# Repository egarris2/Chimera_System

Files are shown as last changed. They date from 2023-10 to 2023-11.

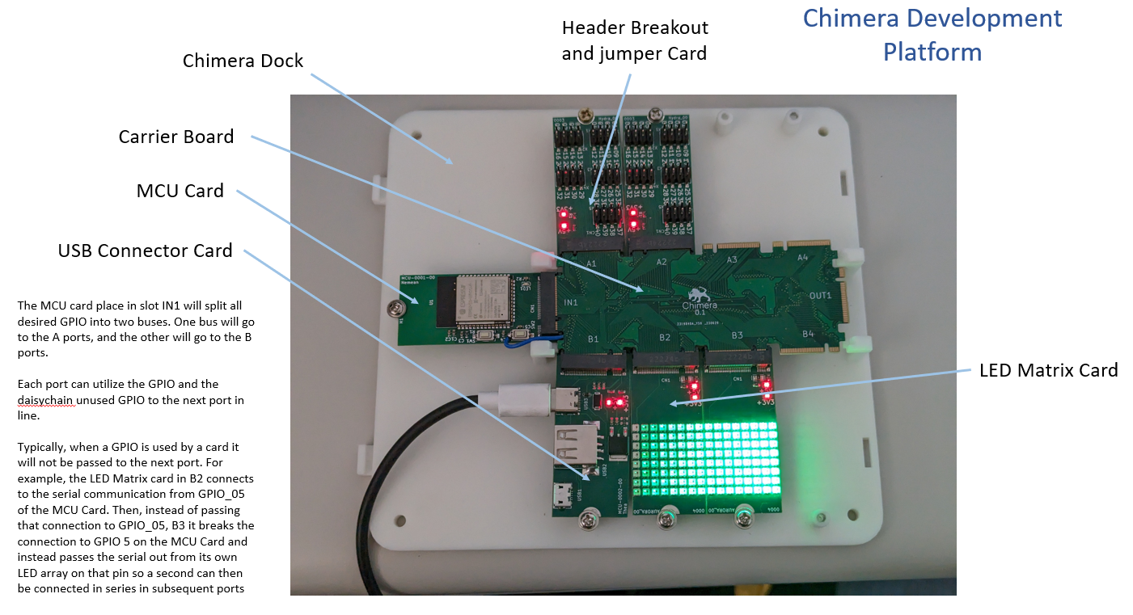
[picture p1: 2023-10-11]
Images/Annotations.png

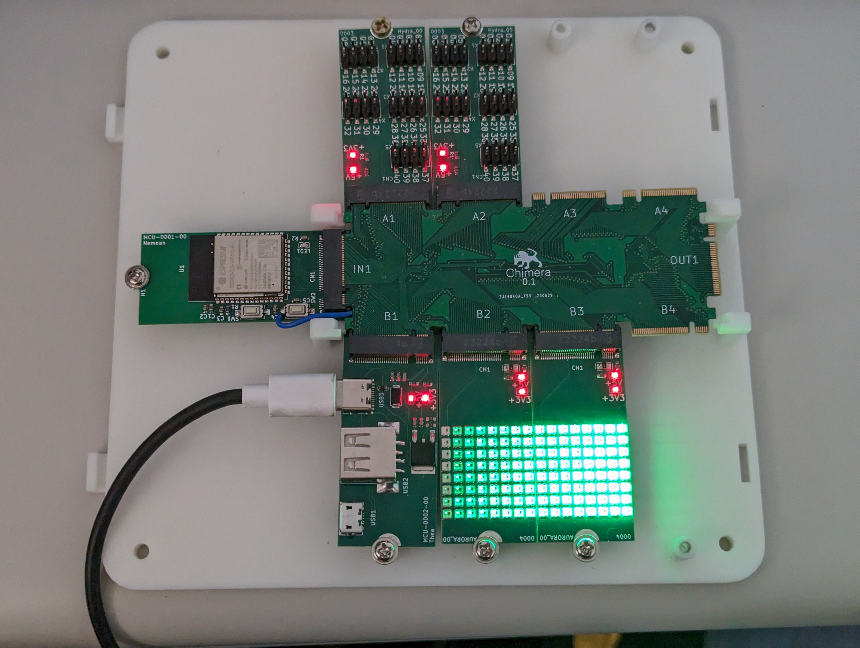
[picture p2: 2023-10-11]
Images/Chimera_System_LEDs.jpg

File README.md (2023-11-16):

View this project on [CADLAB.io](https://cadlab.io/project/27528). 

# Chimera_System
A modular PCB system designed for rapid iteration and extreme flexibility in application.

All PCBs are designed in KiCAD 7. They utilize components that are available from the easyEDA component library which allows for quick generation of manufacturing files for order of assembly from JLCPCB.



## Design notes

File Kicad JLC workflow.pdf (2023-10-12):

Description
This document is a guide to designing a PCBA prototype in Kicad and ordering it through JLCPCB assembly in a way that is quick and easy.

Pre-Requisites and links
Kicad (https://www.kicad.org/) - Open Source EDA software
JLCPCB (https://jlcpcb.com/) - Online PCB fabrication website
JLC Parts Search (https://yaqwsx.github.io/jlcparts/#/) - third party tool for better searching of available SMD assembly parts (github) (https://github.com/yaqwsx/jlcparts) Part import (https://github.com/TousstNicolas/JLC2KiCad_lib) - third party tool for importing JCL component into Kicad Library from command line JLC Export (https://github.com/Bouni/kicad-jlcpcb-tools) - third party tool for exporting BOM and CPL data

Adding JLC compatible parts to Kicad
Search desired components using JLC Parts Search (https://yaqwsx.github.io/jlcparts/#/) to find the LCSC number

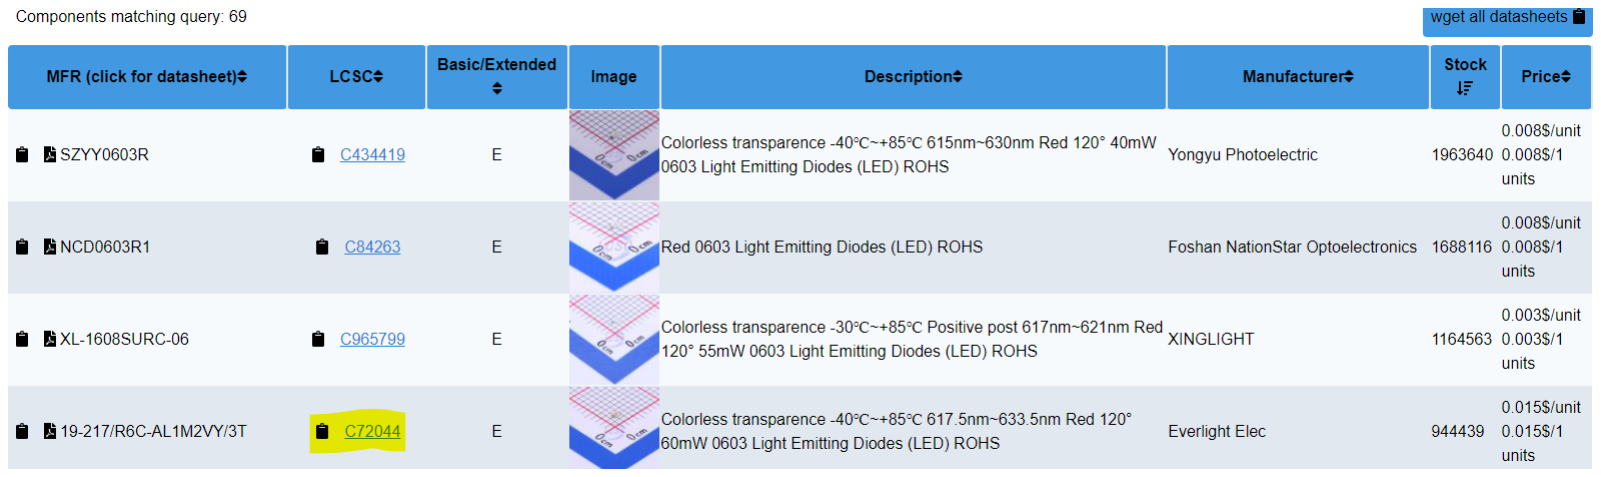
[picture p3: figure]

Import components using Part import. (https://github.com/TousstNicolas/JLC2KiCad_lib)
- Open terminal session in desired directory (e.g. JLC_libraries)
- In the terminal, type command
JLC2KiCadLib C72044 -schematic_lib JLC
- The following folders will be created

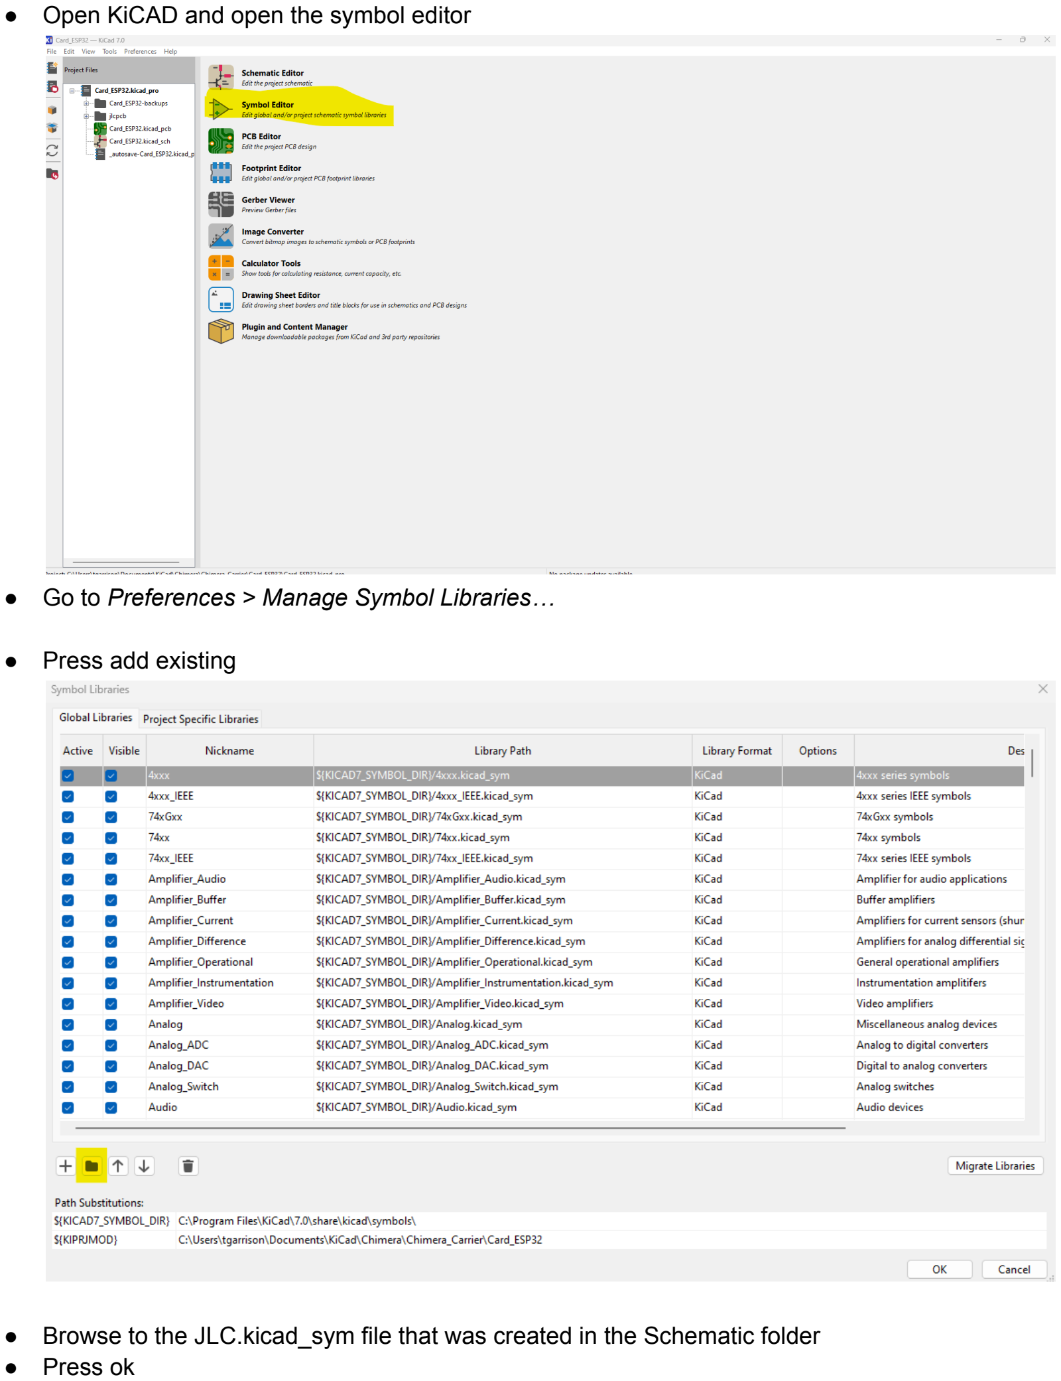
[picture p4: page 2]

- Open KiCAD and open the symbol editor
- Go to Preferences > Manage Symbol Libraries…
- Press add existing
- Browse to the JLC.kicad_sym file that was created in the Schematic folder
- Press ok

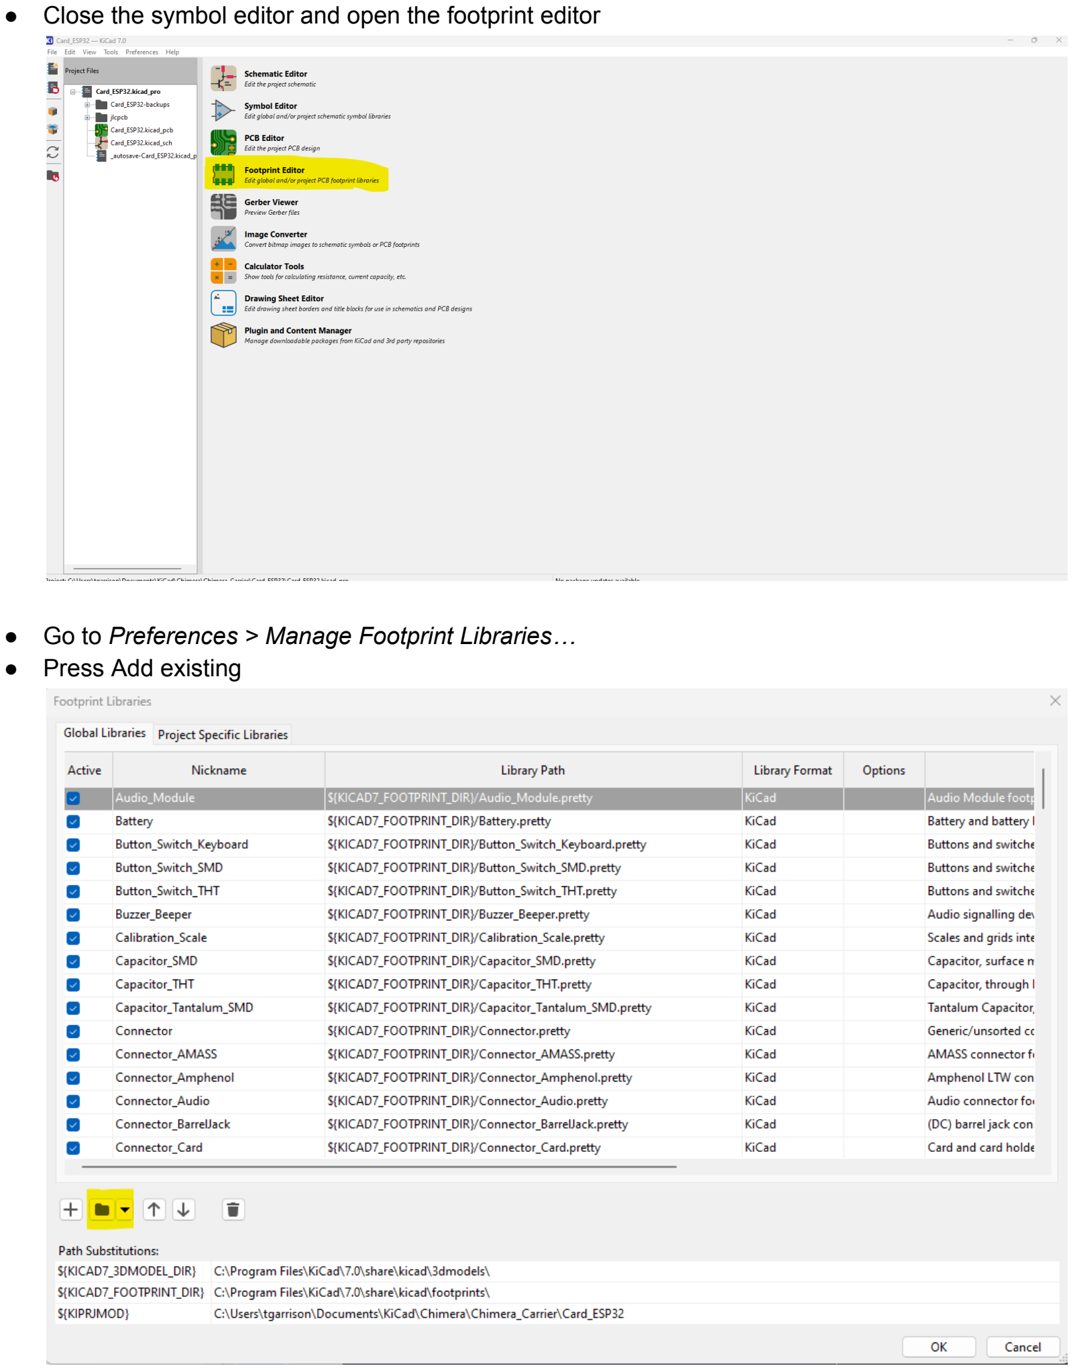
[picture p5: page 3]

- Close the symbol editor and open the footprint editor
- Go to Preferences > Manage Footprint Libraries…
- Press Add existing

- Select the footprint folder that was created (optionally you can give it a nickname)
- Press okay
- To assign the symbol to the footprint, open the symbol editor again
- Select the recently created component/s and open the symbol properties dialogue

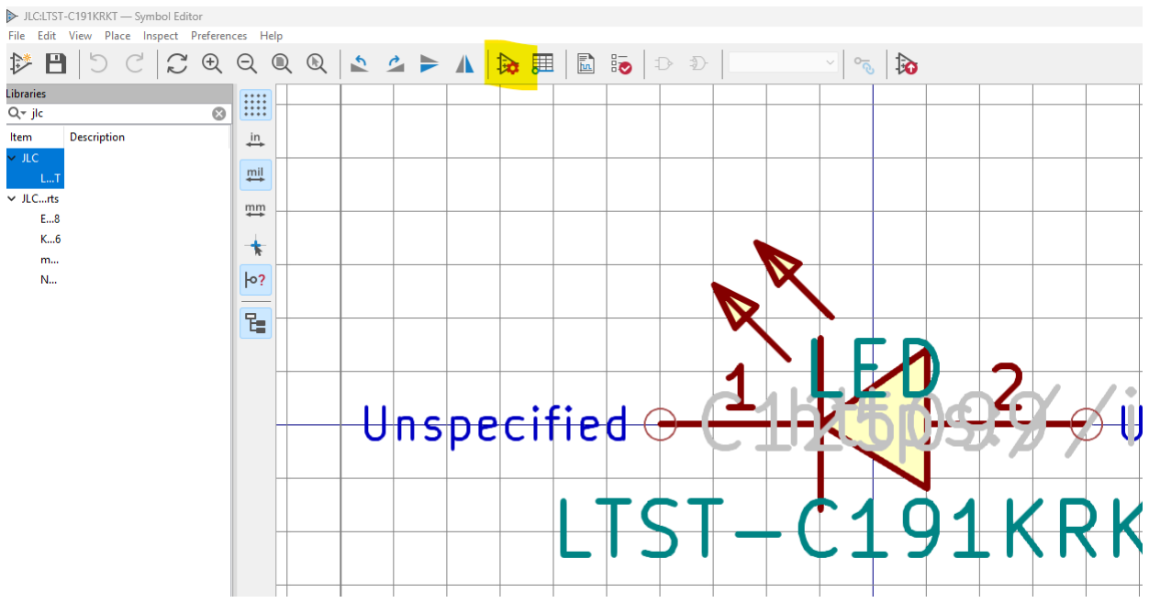
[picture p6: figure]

- Click the icon in the footprint field and select the correct footprint from the previously imported footprint library

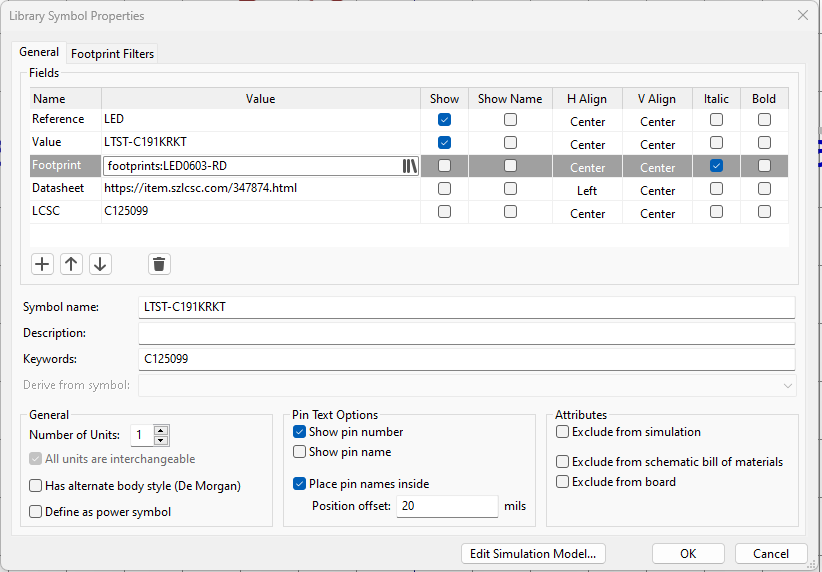
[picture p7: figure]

- This will permanently associate the part with the footprint.
- This step can be eliminated if the created footprint is moved to the Kicad Program files and placed in a footprint.pretty folder .\KiCad\7.0\share\kicad\footprint.pretty (Untested)
- You can now add the part to the schematic with the confidence that when you go to order a prototype from JLCPCB it will automatically be able to be found and assembled when you import BOM and CPL files.

Exporting files for JLC
- After finishing your Kicad Design and are ready to order, you can now press the JLC icon that was added to Kicad after you added the JLC Export (https://github.com/Bouni/kicad-jlcpcb-tools) tool to Kicad.
- Here you can review that all of your parts are recognized as JLC assembly components by their CXXXXX number.
- Press Generate fabrication files and zip them into a folder to drag into JLCPCB (https://jlcpcb.com/) when ready to order. This should let you order the prototype with no further work unless one of the parts you used has gone out of stock.

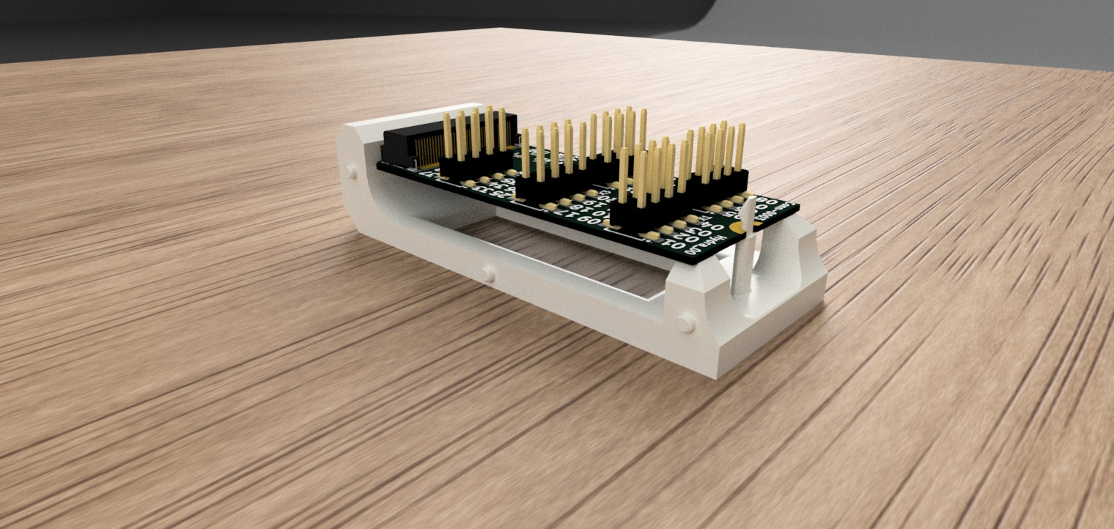
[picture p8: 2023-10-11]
Model_Chimera_Card_Holder/Chimera_Card_Holder_white_nubs.png

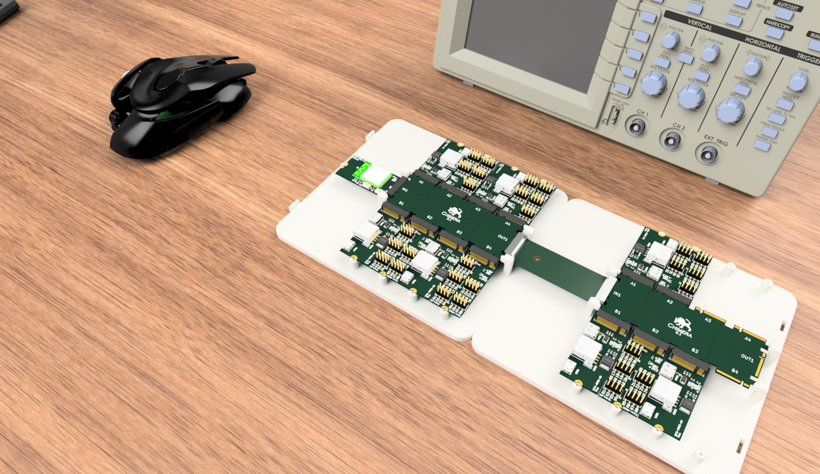
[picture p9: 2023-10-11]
PCB_Chimera_Card_Examples/Chimera_0003_Hydra_CONN_Headers/3D/Chimera_Dock v5.png

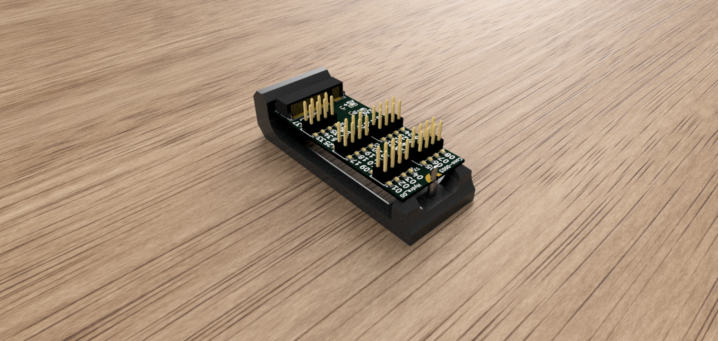
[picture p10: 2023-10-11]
Model_Chimera_Card_Holder/Chimera_Card_Holder_black.png

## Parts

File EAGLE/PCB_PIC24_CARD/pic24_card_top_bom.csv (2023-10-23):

Comment | Designator | Footprint | LCSC Part #
12MHz | Y1 | FA238
3k3 | R5 R6 | R0402_NIBE | C3969551
10k | R1 R4 R7 | R0402_NIBE | C2838653
10u | C10 | C0805 | C882505
16p | C1 C5 | C0402_NIBE | C161307
100n | C2 C3 C4 C6 C7 C8 C9 C11 | C0402_NIBE | C327273
470R | R3 R8 | R0402_NIBE | C606172
820R | R2 | R0402_NIBE | C227421
CONN_SMD_67P-P0.5-V_NASB0-S6701-TS50 | X1 | CONN_SMD_67P-P0.5-V_NASB0-S6701-TS50 | C367024
LED_YELLOW | STATUS | R0603 | C511086
M.2_MKEY_FINGERS | X2 | M.2_MKEY_FINGERS
MOUNTING_3M_3.2MM | M1 | MOUNTING_3M_3.2MM
PIC24FJ256GL410 | IC1 | PIC24FJ256GL410 | C1015827
XR3072XID-F | IC2 | SOIC8

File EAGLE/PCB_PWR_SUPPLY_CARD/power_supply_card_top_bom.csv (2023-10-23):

Comment | Designator | Footprint | LCSC Part #
2R 1W | R3 | R2512 | C105100
4u7 100V | C3 | C1210 | C385987
10u | C13 C14 | C0603 | C4555498603
10u | L1 | L4532P | C99792
10u 50V | C5 C6 C7 C8 | C1210 | C412619
22k | R5 | R0402_NIBE | C416374
47k | R4 R7 | R0402_NIBE | C4076535
100n 50V | C4 C9 C11 | C0603 | C2929177
100u | L2 | ASPI-8040S | C187495
130k | R8 | R0402_NIBE | C4028083
150n | C10 | C0603 | C913573
150n | C12 | C0402_NIBE | C51554
200k | R6 | R0402_NIBE | C2906866
220k | R9 | R0402_NIBE | C168214
470R | R2 | R0603 | C23179
74404063470 | L3 | 74404063470 | C6404593
B72520T0400K062 | R1 | R1206 | C210939
CONN_SMD_67P-P0.5-V_NASB0-S6701-TS50 | X1 | CONN_SMD_67P-P0.5-V_NASB0-S6701-TS50 | C367024
DSS16U | D2 D3 | SOD123F | C3020461
LED_GREEN | LED1 | R0603 | C125099
LIN_REG_ADJ_SOT223 | IC1 | SOT223 | C108496
M.2_MKEY_FINGERS | X2 | M.2_MKEY_FINGERS | na
MOUNTING_3M_3.2MM | M1 | MOUNTING_3M_3.2MM | na
RS1J | D1 | DO-214AC(SMA) | C154794
ST1S14PHR | U1 U2 | HSOP8_STM | C84130
Phoenix | X3 | 1751248 | C89122
220u 50V | C1 | 5p 10d | C134649

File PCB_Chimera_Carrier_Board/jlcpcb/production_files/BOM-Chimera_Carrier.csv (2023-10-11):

Comment | Designator | Footprint | LCSC
Bus_M.2_Socket_B | B1 | NGFF_B
Bus_M.2_Socket_B | A2 | NGFF_B
Bus_M.2_Socket_B | IN1 | NGFF_B
Bus_M.2_Socket_B | OUT1 | NGFF_B
Bus_M.2_Socket_B | A3 | NGFF_B
Bus_M.2_Socket_B | B3 | NGFF_B
Bus_M.2_Socket_B | B2 | NGFF_B
Bus_M.2_Socket_B | B4 | NGFF_B
Bus_M.2_Socket_B | A1 | NGFF_B
Bus_M.2_Socket_B | A4 | NGFF_B

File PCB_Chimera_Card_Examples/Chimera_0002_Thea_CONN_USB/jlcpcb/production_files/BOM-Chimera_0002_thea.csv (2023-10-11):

Comment | Designator | Footprint | LCSC
micro_USBFemale | USB1 | MICRO-USB-SMD_5P-P0.65-H-F_C10418 | C10418
LTST-C191KRKT | LED1,LED2 | LED0603-RD | C125099
GT-USB-7010ASV | U1 | USB-C-SMD_G-SWITCH_GT-USB-7010ASV | C2988369
SMAJ5_0CA_C353441 | U3 | SMA_L4.3-W2.5-LS5.0-BI | C353441
NASB0-S6701-TS50 | CN1 | CONN-SMD_67P-P0.50-V_NASB0-S6701-TS50 | C367024
A_F_LCPTrue_color1_2pillar_C42605 | USB2 | USB-A-SMD_USB-M-32 | C42605
LM317_C77880 | Q1 | TO-252-2_L6.6-W6.1-P4.57-LS9.9-TL-CW | C77880
BSMD0603-050-6V | F1 | F0603 | C883095
MountingHole | H1 | MountingHole_3.2mm_M3_Pad_TopBottom
1n | C3 | C_0603_1608Metric
470R | R3 | R_0603_1608Metric
1n | C4 | C_0603_1608Metric
~ | U2 | NGFF_M
470R | R4 | R_0603_1608Metric
470R | R1 | R_0603_1608Metric
470R | R2 | R_0603_1608Metric
1n | C5 | C_0603_1608Metric
100n | C2 | C_0603_1608Metric
10u | C1 | C_0603_1608Metric

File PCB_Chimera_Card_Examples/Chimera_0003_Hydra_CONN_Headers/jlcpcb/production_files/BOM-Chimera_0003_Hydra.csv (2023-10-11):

Comment | Designator | Footprint | LCSC
LTST-C191KRKT | LED1,LED2 | LED0603-RD | C125099
470R | R1,R2 | R_0603_1608Metric | C23179
PZ254-2-04-S | X1,X2,X3,X4,X5 | HDR-SMD_8P-P2.54-V-M-R2-C4-LS7.4 | C3294462
NASB0-S6701-TS50 | CN1 | CONN-SMD_67P-P0.50-V_NASB0-S6701-TS50 | C367024
MountingHole | H2 | MountingHole_3.2mm_M3_Pad_TopBottom
~ | U2 | NGFF_M

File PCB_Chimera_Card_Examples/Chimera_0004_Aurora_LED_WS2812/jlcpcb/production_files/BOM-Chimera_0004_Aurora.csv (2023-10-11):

Comment | Designator | Footprint | LCSC
LTST-C191KRKT | LED1,LED2 | LED0603-RD | C125099
TLC-PSMD010 | F1 | F0805 | C261939
NASB0-S6701-TS50 | CN1 | CONN-SMD_67P-P0.50-V_NASB0-S6701-TS50 | C367024
WS2812B-2020 | LED10,LED11,LED12,LED13,LED14,LED15,LED16,LED17,LED18,LED19,LED20,LED21,LED22,LED23,LED24,LED25,LED26,LED27,LED28,LED29,LED3,LED30,LED31,LED32,LED33,LED34,LED35,LED36,LED37,LED38,LED39,LED4,LED40,LED41,LED42,LED43,LED44,LED45,LED46,LED47,LED48,LED49,LED5,LED50,LED51,LED52,LED53,LED55,LED56,LED57,LED59,LED6,LED60,LED61,LED63,LED64,LED65,LED67,LED68,LED7,LED71,LED72,LED8,LED9 | LED-SMD_4P-L2.0-W2.0-TL_WS2812B-2020 | C965555
MountingHole | H1 | MountingHole_3.2mm_M3_Pad_TopBottom
100n | C70 | C_0402_1005Metric
100n | C69 | C_0402_1005Metric
100n | C66 | C_0402_1005Metric
100n | C65 | C_0402_1005Metric
100n | C63 | C_0402_1005Metric
100n | C62 | C_0402_1005Metric
100n | C61 | C_0402_1005Metric
100n | C59 | C_0402_1005Metric
100n | C58 | C_0402_1005Metric
100n | C57 | C_0402_1005Metric
100n | C55 | C_0402_1005Metric
100n | C54 | C_0402_1005Metric
100n | C53 | C_0402_1005Metric
100n | C51 | C_0402_1005Metric
100n | C50 | C_0402_1005Metric
100n | C49 | C_0402_1005Metric
100n | C48 | C_0402_1005Metric
100n | C47 | C_0402_1005Metric
100n | C46 | C_0402_1005Metric
100n | C45 | C_0402_1005Metric
100n | C44 | C_0402_1005Metric
100n | C43 | C_0402_1005Metric
100n | C42 | C_0402_1005Metric
100n | C41 | C_0402_1005Metric
100n | C40 | C_0402_1005Metric
100n | C39 | C_0402_1005Metric
100n | C38 | C_0402_1005Metric
100n | C37 | C_0402_1005Metric
100n | C36 | C_0402_1005Metric
100n | C35 | C_0402_1005Metric
100n | C34 | C_0402_1005Metric
100n | C33 | C_0402_1005Metric
100n | C32 | C_0402_1005Metric
100n | C31 | C_0402_1005Metric
100n | C30 | C_0402_1005Metric
100n | C29 | C_0402_1005Metric
100n | C28 | C_0402_1005Metric
100n | C27 | C_0402_1005Metric
100n | C26 | C_0402_1005Metric
100n | C25 | C_0402_1005Metric
100n | C7 | C_0402_1005Metric
100n | C2 | C_0402_1005Metric
100n | C4 | C_0402_1005Metric
100n | C5 | C_0402_1005Metric
100n | C6 | C_0402_1005Metric
100n | C22 | C_0402_1005Metric
100n | C10 | C_0402_1005Metric
100n | C20 | C_0402_1005Metric
100n | C1 | C_0402_1005Metric
100n | C3 | C_0402_1005Metric
100n | C9 | C_0402_1005Metric
100n | C11 | C_0402_1005Metric
100n | C12 | C_0402_1005Metric
100n | C13 | C_0402_1005Metric
100n | C14 | C_0402_1005Metric
100n | C15 | C_0402_1005Metric
100n | C17 | C_0402_1005Metric
100n | C19 | C_0402_1005Metric
100n | C18 | C_0402_1005Metric
100n | C16 | C_0402_1005Metric
100n | C21 | C_0402_1005Metric
100n | C23 | C_0402_1005Metric
100n | C8 | C_0402_1005Metric
100n | C24 | C_0402_1005Metric
~ | U2 | NGFF_M
470R | R1 | R_0603_1608Metric
470R | R2 | R_0603_1608Metric

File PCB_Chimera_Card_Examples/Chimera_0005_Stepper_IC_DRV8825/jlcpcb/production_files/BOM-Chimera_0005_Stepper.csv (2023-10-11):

Comment | Designator | Footprint | LCSC
LTST-C191KRKT | LED1,LED2 | LED0603-RD | C125099
TLC-PSMD010 | F1 | F0805 | C261939
DB126V-5_0-6P-GN | U3 | CONN-TH_DB126V-5.0-6P-GN | C2682301
NASB0-S6701-TS50 | CN1 | CONN-SMD_67P-P0.50-V_NASB0-S6701-TS50 | C367024
DRV8825PWPR | U1 | HTSSOP-28_L9.7-W4.4-P0.65-LS6.4-BL-EP | C81582
0.01 uF | C6 | C_0603_1608Metric
NM | R17 | R_0603_1608Metric
NM | R14 | R_0603_1608Metric
0.2R | R5 | R_0603_1608Metric
~ | U2 | NGFF_M
10k | R7 | R_0603_1608Metric
1M | R3 | R_0603_1608Metric
470R | R1 | R_0603_1608Metric
100 uF | C5 | CP_Elec_6.3x5.4_Nichicon
470R | R2 | R_0603_1608Metric
0.1 uF | C3 | C_0603_1608Metric
NM | R18 | R_0603_1608Metric
0.2R | R4 | R_0603_1608Metric
NM | R13 | R_0603_1608Metric
NM | R23 | R_0603_1608Metric
NM | R10 | R_0603_1608Metric
0.1 uF | C1 | C_0603_1608Metric
10k | R11 | R_0603_1608Metric
0.1 uF | C2 | C_0603_1608Metric
NM | R9 | R_0603_1608Metric
MountingHole | H1 | MountingHole_3.2mm_M3_Pad_TopBottom
3k6 | R8 | R_0603_1608Metric
NM | R19 | R_0603_1608Metric
0.47 uF | C7 | C_0603_1608Metric
47k | R6 | R_0603_1608Metric
NM | R16 | R_0603_1608Metric
10k | R12 | R_0603_1608Metric

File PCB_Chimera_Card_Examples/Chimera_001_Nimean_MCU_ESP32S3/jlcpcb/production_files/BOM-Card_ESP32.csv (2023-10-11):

Comment | Designator | Footprint | LCSC
K2-1107ST-A4SW-06 | SW1,SW2 | KEY-SMD_L6.2-W3.6-LS8.0 | C118141
LTST-C191KRKT | LED1 | LED0603-RD | C125099
10k | R1 | R_0603_1608Metric | C13564
100n | C2,C4,C5 | C_0603_1608Metric | C1591
1u | C3 | C_0603_1608Metric | C1592
1k | R2 | R_0603_1608Metric | C1603
ESP32-S3-WROOM-1-N8 | U1 | WIFIM-SMD_ESP32-S3-WROOM-1-N8 | C2913198
NASB0-S6701-TS50 | CN1 | CONN-SMD_67P-P0.50-V_NASB0-S6701-TS50 | C367024
22u | C1 | C_0603_1608Metric | C59461
~ | U2 | NGFF_M
MountingHole | H1 | MountingHole_2.5mm_Pad_TopBottom

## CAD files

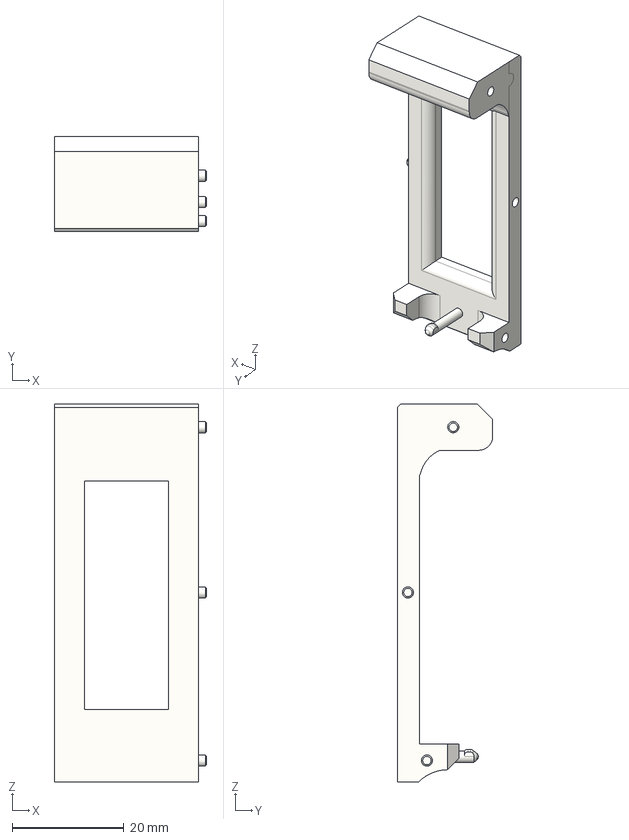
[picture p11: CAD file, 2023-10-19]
Model_Chimera_Card_Holder/Chimera_Card_Holder_03.step
27.2 x 17.0 x 67.6 mm

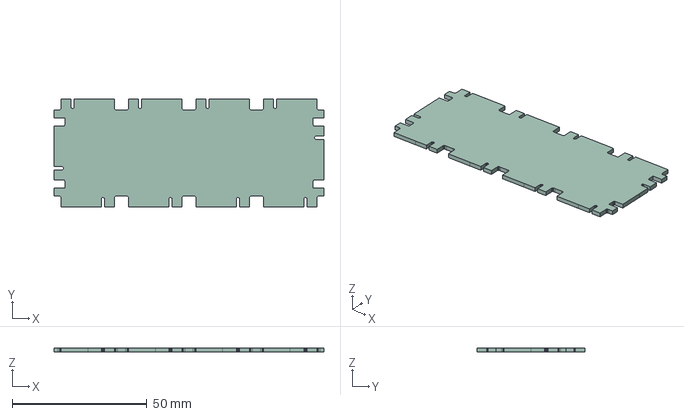
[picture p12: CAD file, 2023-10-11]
PCB_Chimera_Carrier_Board/3D/Chimera_Carrier.step
100.0 x 40.0 x 1.58 mm

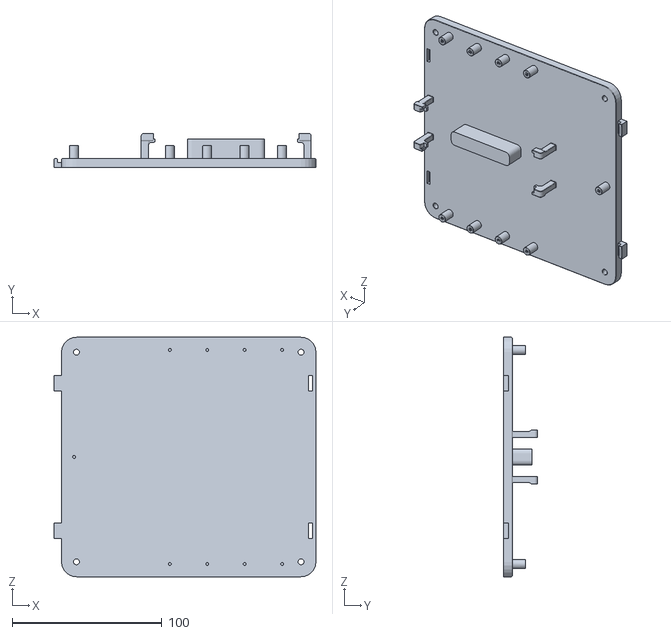
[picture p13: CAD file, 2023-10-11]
Model_Chimera_Dock/Chimera_Dock v6.stl
175.0 x 23.0 x 160.0

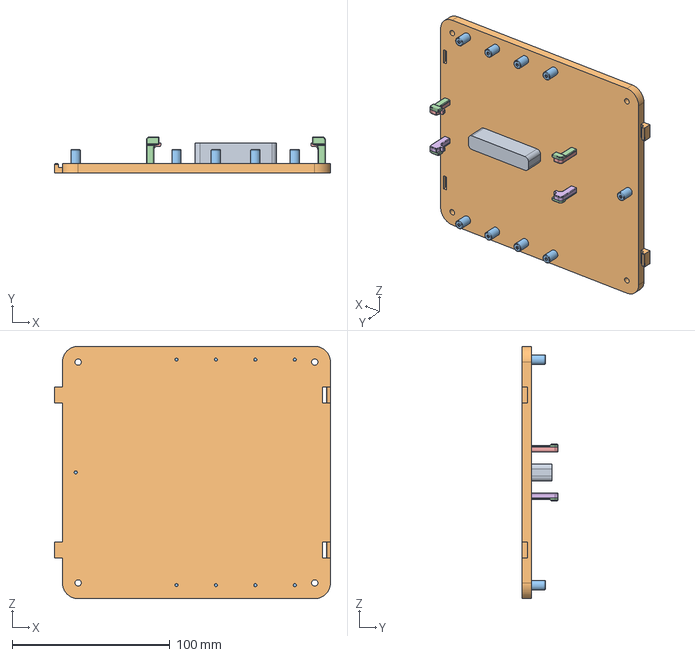
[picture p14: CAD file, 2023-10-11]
Model_Chimera_Dock/Chimera_Dock.step
175.0 x 23.0 x 160.0 mm

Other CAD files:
Model_Chimera_Dock/Chimera_0001_Nimean v1.step
Model_Chimera_Card_Holder/Chimera_Card_Holder_03.stl

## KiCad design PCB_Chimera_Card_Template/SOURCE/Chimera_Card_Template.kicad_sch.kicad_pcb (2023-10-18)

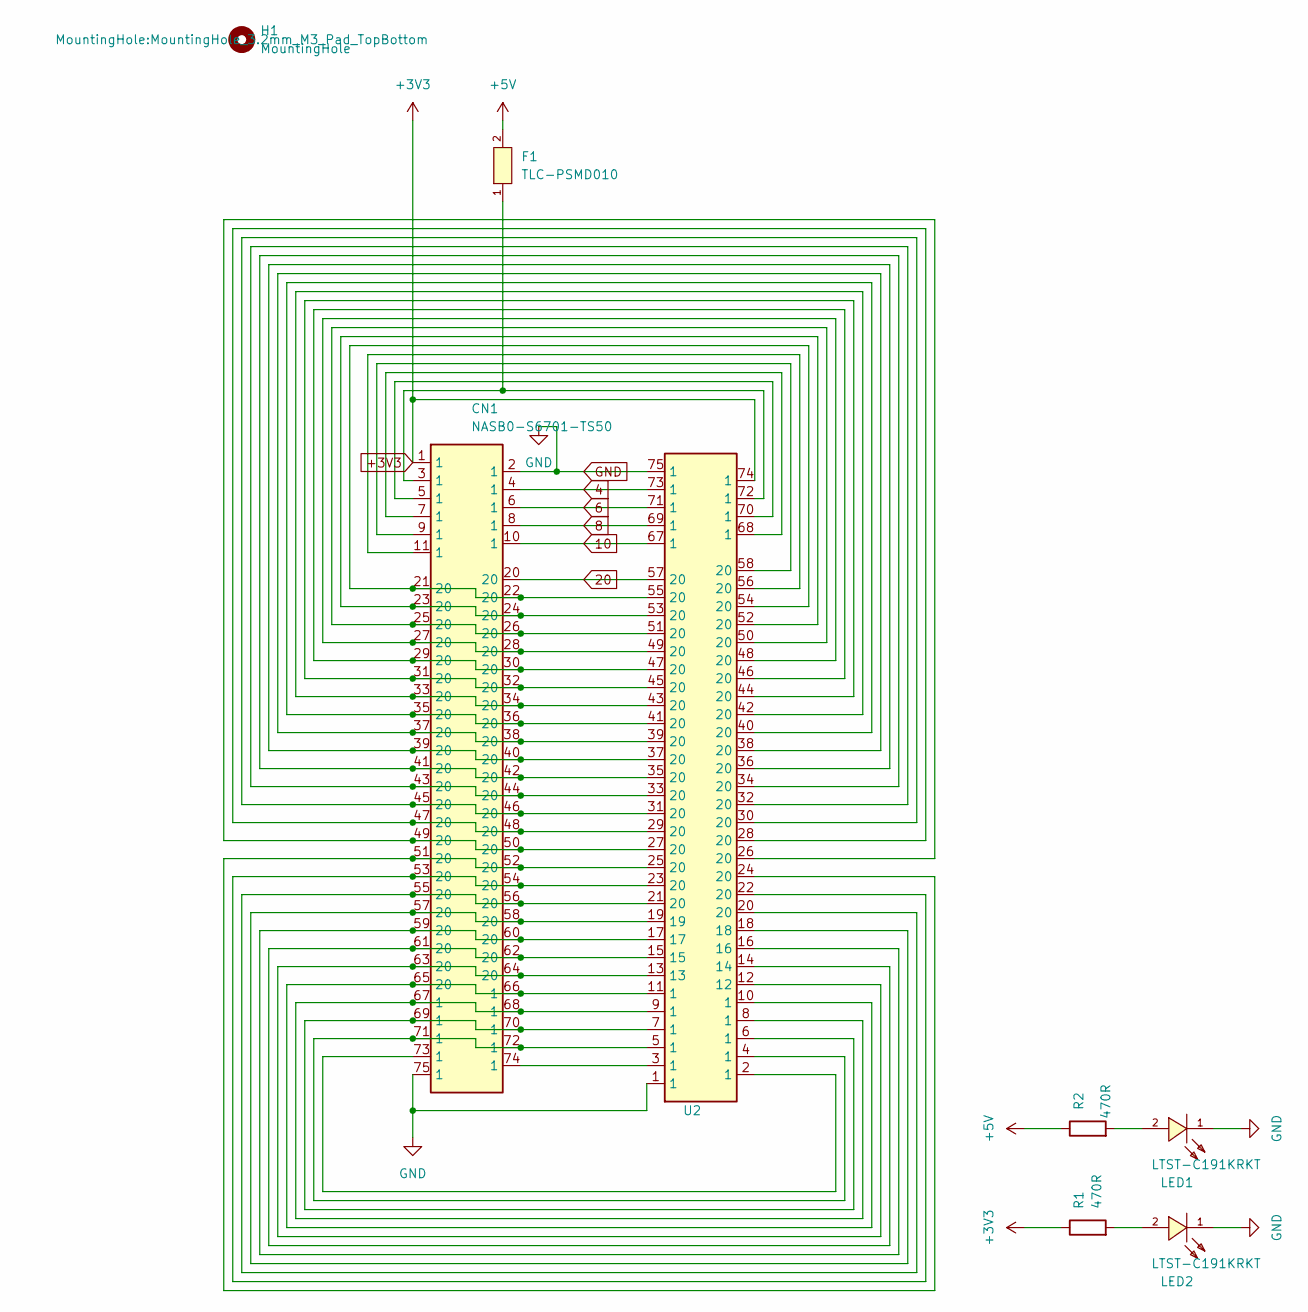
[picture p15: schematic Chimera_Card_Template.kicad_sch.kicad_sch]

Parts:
CN1: NASB0-S6701-TS50; CONN-SMD_67P-P0.50-V_NASB0-S6701-TS50; LCSC C367024
F1: TLC-PSMD010; F0805; LCSC C261939
H1: MountingHole; MountingHole_3.2mm_M3_Pad_TopBottom
LED1, LED2: LTST-C191KRKT; LED0603-RD; LCSC C125099
R1, R2: 470R; R_0603_1608Metric
U2: NGFF_M

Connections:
4: CN1.4 (1), U2.73 (1)
6: CN1.6 (1), U2.71 (1)
8: CN1.8 (1), U2.69 (1)
10: CN1.10 (1), U2.67 (1)
20: CN1.20, U2.57 (20)
+3V3: CN1.1, R1.1, U2.74 (1)
+5V: F1.2, R2.1
GND: CN1.2 (1), CN1.75 (1), LED1.1 (-), LED2.1 (-), U2.1, U2.75 (1)
unnamed: CN1.3 (1), F1.1, U2.72 (1)
unnamed: CN1.5 (1), U2.70 (1)
unnamed: CN1.7 (1), U2.68 (1)
unnamed: CN1.9 (1), U2.58 (20)
unnamed: CN1.11 (1), U2.56 (20)
unnamed: CN1.65 (20), CN1.66 (1), U2.10 (1), U2.11 (1)
unnamed: CN1.67 (1), CN1.68 (1), U2.8 (1), U2.9 (1)
unnamed: CN1.69 (1), CN1.70 (1), U2.6 (1), U2.7 (1)
unnamed: CN1.71 (1), CN1.72 (1), U2.4 (1), U2.5 (1)
unnamed: CN1.73 (1), U2.2 (1)
unnamed: CN1.74 (1), U2.3 (1)
unnamed: CN1.21 (20), CN1.22 (20), U2.54 (20), U2.55 (20)
unnamed: CN1.23 (20), CN1.24 (20), U2.52 (20), U2.53 (20)
unnamed: CN1.25 (20), CN1.26 (20), U2.50 (20), U2.51 (20)
unnamed: CN1.27 (20), CN1.28 (20), U2.48 (20), U2.49 (20)
unnamed: CN1.29 (20), CN1.30 (20), U2.46 (20), U2.47 (20)
unnamed: CN1.31 (20), CN1.32 (20), U2.44 (20), U2.45 (20)
unnamed: CN1.33 (20), CN1.34 (20), U2.42 (20), U2.43 (20)
unnamed: CN1.35 (20), CN1.36 (20), U2.40 (20), U2.41 (20)
unnamed: CN1.37 (20), CN1.38 (20), U2.38 (20), U2.39 (20)
unnamed: CN1.39 (20), CN1.40 (20), U2.36 (20), U2.37 (20)
unnamed: CN1.41 (20), CN1.42 (20), U2.34 (20), U2.35 (20)
unnamed: CN1.43 (20), CN1.44 (20), U2.32 (20), U2.33 (20)
unnamed: CN1.45 (20), CN1.46 (20), U2.30 (20), U2.31 (20)
unnamed: CN1.47 (20), CN1.48 (20), U2.28 (20), U2.29 (20)
unnamed: CN1.49 (20), CN1.50 (20), U2.26 (20), U2.27 (20)
unnamed: CN1.51 (20), CN1.52 (20), U2.24 (20), U2.25 (20)
unnamed: CN1.53 (20), CN1.54 (20), U2.22 (20), U2.23 (20)
unnamed: CN1.55 (20), CN1.56 (20), U2.20, U2.21 (20)
unnamed: CN1.57 (20), CN1.58 (20), U2.18, U2.19
unnamed: CN1.59 (20), CN1.60 (20), U2.16, U2.17
unnamed: CN1.61 (20), CN1.62 (20), U2.14, U2.15
unnamed: CN1.63 (20), CN1.64 (20), U2.12, U2.13
unnamed: LED1.2 (+), R2.2
unnamed: LED2.2 (+), R1.2

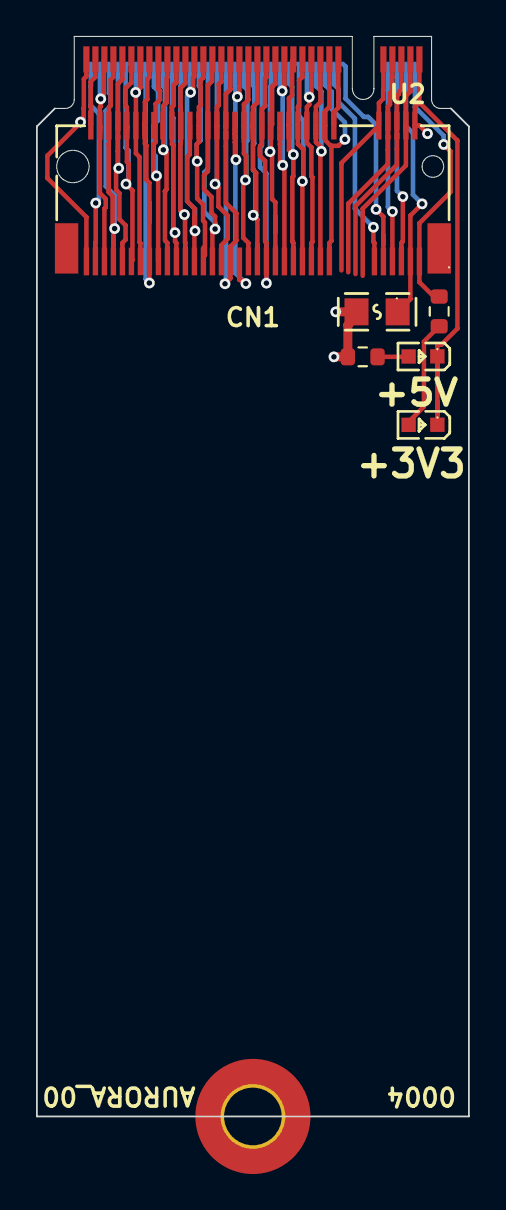
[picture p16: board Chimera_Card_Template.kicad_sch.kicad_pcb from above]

Board: 4 copper layers, 24.0 x 60.0 mm, 8 parts (0 on the bottom side), 43 nets.

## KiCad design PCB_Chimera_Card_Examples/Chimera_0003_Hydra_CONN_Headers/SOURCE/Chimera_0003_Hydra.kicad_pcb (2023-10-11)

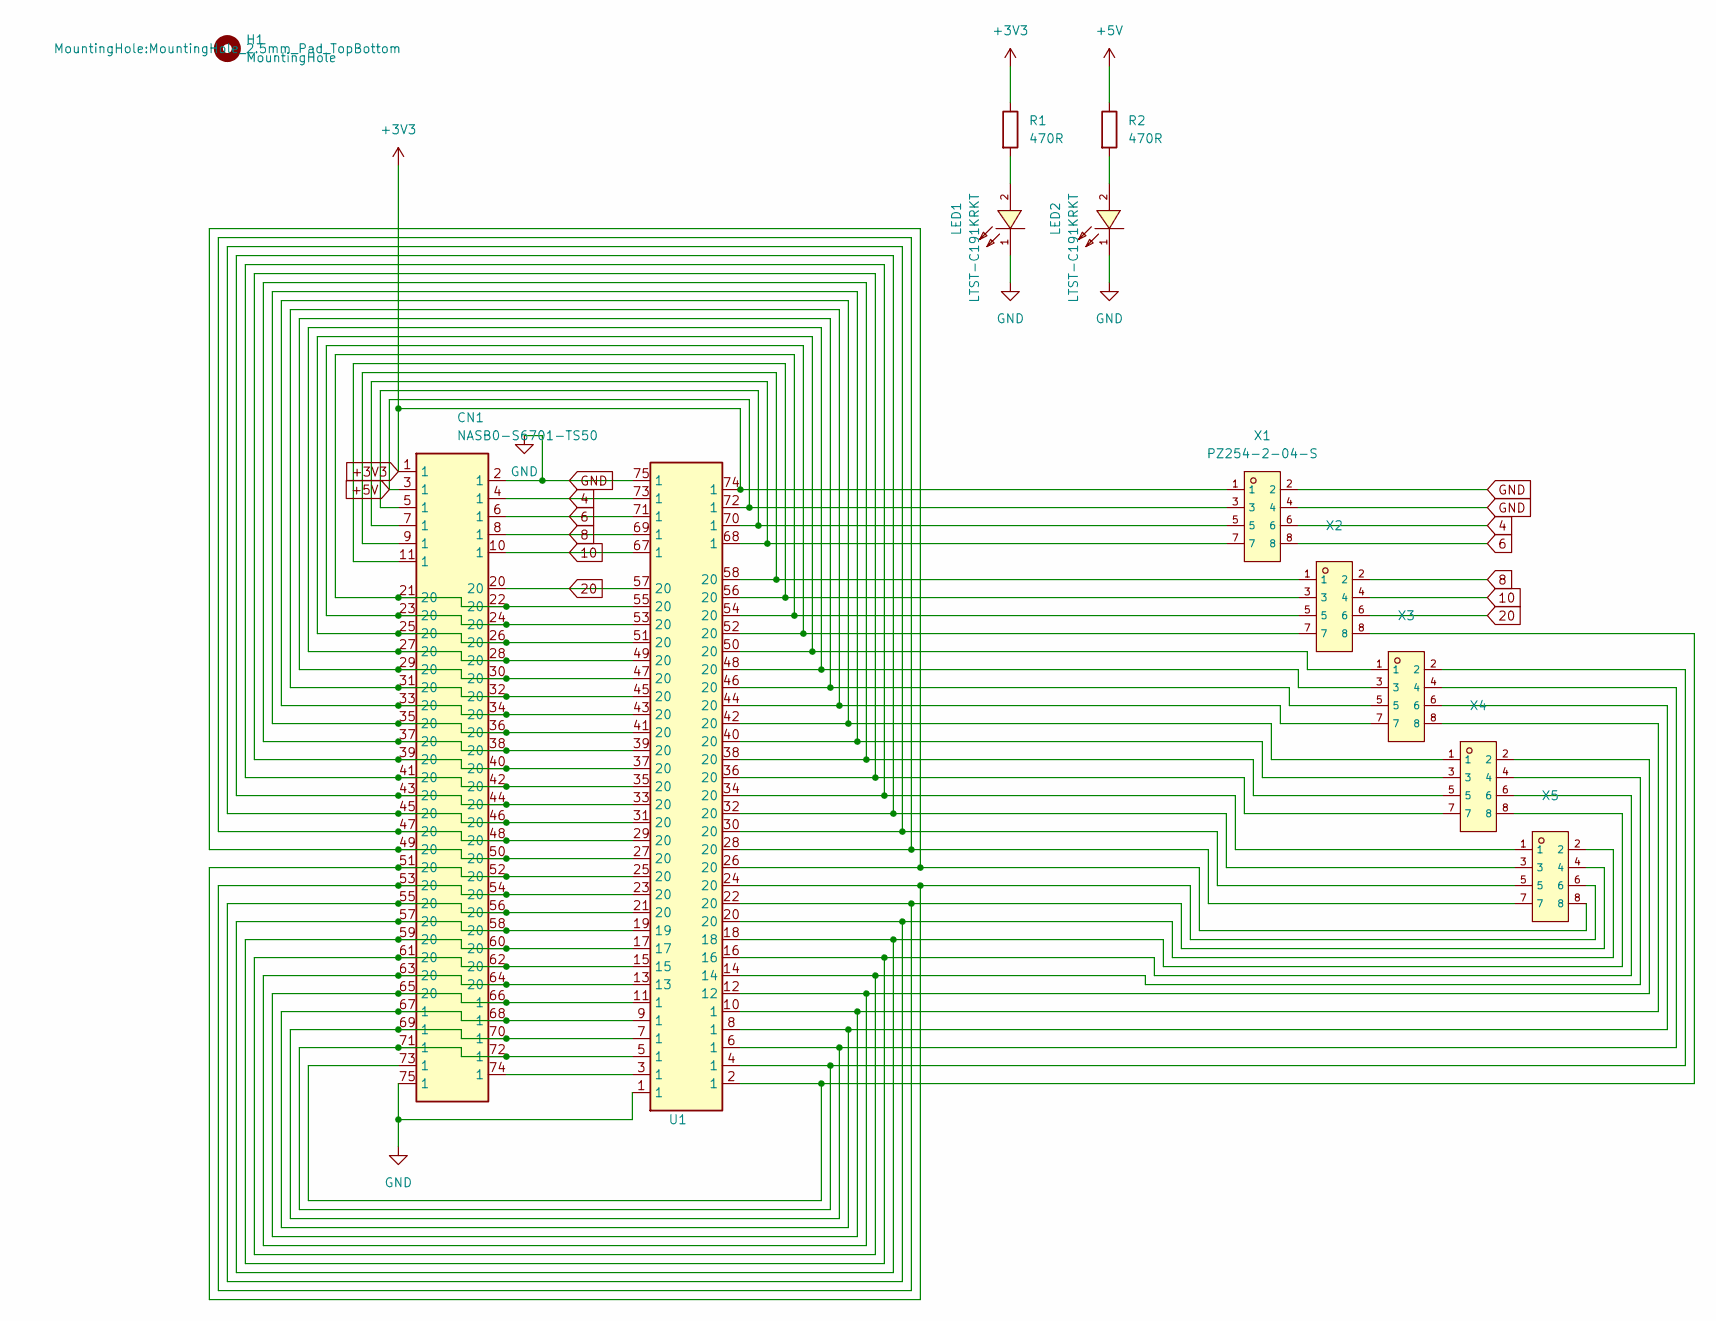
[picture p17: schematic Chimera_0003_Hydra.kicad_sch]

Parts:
CN1: NASB0-S6701-TS50; CONN-SMD_67P-P0.50-V_NASB0-S6701-TS50; LCSC C367024
H1: MountingHole; MountingHole_2.5mm_Pad_TopBottom
LED1, LED2: LTST-C191KRKT; LED0603-RD; LCSC C125099
R1, R2: 470R; R_0603_1608Metric
U1: NGFF_M
X1, X2, X3, X4, X5: PZ254-2-04-S; HDR-SMD_8P-P2.54-V-M-R2-C4-LS7.4; LCSC C3294462

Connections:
4: CN1.4 (1), U1.73 (1), X1.6
6: CN1.6 (1), U1.71 (1), X1.8
8: CN1.8 (1), U1.69 (1), X2.2
10: CN1.10 (1), U1.67 (1), X2.4
20: CN1.20, U1.57 (20), X2.6
+3V3: CN1.1, R1.1, U1.74 (1), X1.1
+5V: CN1.3 (1), R2.1, U1.72 (1), X1.3
GND: CN1.2 (1), CN1.75 (1), LED1.1 (-), LED2.1 (-), U1.1, U1.75 (1), X1.2, X1.4
unnamed: CN1.5 (1), U1.70 (1), X1.5
unnamed: CN1.7 (1), U1.68 (1), X1.7
unnamed: CN1.9 (1), U1.58 (20), X2.1
unnamed: CN1.11 (1), U1.56 (20), X2.3
unnamed: CN1.65 (20), CN1.66 (1), U1.10 (1), U1.11 (1), X3.8
unnamed: CN1.67 (1), CN1.68 (1), U1.8 (1), U1.9 (1), X3.6
unnamed: CN1.69 (1), CN1.70 (1), U1.6 (1), U1.7 (1), X3.4
unnamed: CN1.71 (1), CN1.72 (1), U1.4 (1), U1.5 (1), X3.2
unnamed: CN1.73 (1), U1.2 (1), X2.8
unnamed: CN1.74 (1), U1.3 (1)
unnamed: CN1.21 (20), CN1.22 (20), U1.54 (20), U1.55 (20), X2.5
unnamed: CN1.23 (20), CN1.24 (20), U1.52 (20), U1.53 (20), X2.7
unnamed: CN1.25 (20), CN1.26 (20), U1.50 (20), U1.51 (20), X3.1
unnamed: CN1.27 (20), CN1.28 (20), U1.48 (20), U1.49 (20), X3.3
unnamed: CN1.29 (20), CN1.30 (20), U1.46 (20), U1.47 (20), X3.5
unnamed: CN1.31 (20), CN1.32 (20), U1.44 (20), U1.45 (20), X3.7
unnamed: CN1.33 (20), CN1.34 (20), U1.42 (20), U1.43 (20), X4.1
unnamed: CN1.35 (20), CN1.36 (20), U1.40 (20), U1.41 (20), X4.3
unnamed: CN1.37 (20), CN1.38 (20), U1.38 (20), U1.39 (20), X4.5
unnamed: CN1.39 (20), CN1.40 (20), U1.36 (20), U1.37 (20), X4.7
unnamed: CN1.41 (20), CN1.42 (20), U1.34 (20), U1.35 (20), X5.1
unnamed: CN1.43 (20), CN1.44 (20), U1.32 (20), U1.33 (20), X5.3
unnamed: CN1.45 (20), CN1.46 (20), U1.30 (20), U1.31 (20), X5.5
unnamed: CN1.47 (20), CN1.48 (20), U1.28 (20), U1.29 (20), X5.7
unnamed: CN1.49 (20), CN1.50 (20), U1.26 (20), U1.27 (20), X5.8
unnamed: CN1.51 (20), CN1.52 (20), U1.24 (20), U1.25 (20), X5.6
unnamed: CN1.53 (20), CN1.54 (20), U1.22 (20), U1.23 (20), X5.4
unnamed: CN1.55 (20), CN1.56 (20), U1.20, U1.21 (20), X5.2
unnamed: CN1.57 (20), CN1.58 (20), U1.18, U1.19, X4.8
unnamed: CN1.59 (20), CN1.60 (20), U1.16, U1.17, X4.6
unnamed: CN1.61 (20), CN1.62 (20), U1.14, U1.15, X4.4
unnamed: CN1.63 (20), CN1.64 (20), U1.12, U1.13, X4.2
unnamed: LED1.2 (+), R1.2
unnamed: LED2.2 (+), R2.2

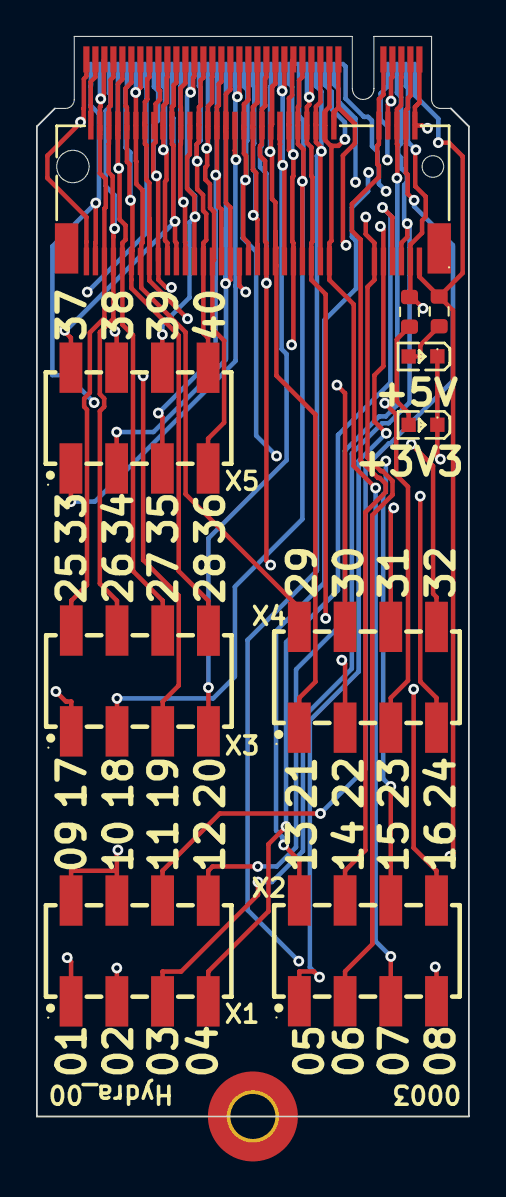
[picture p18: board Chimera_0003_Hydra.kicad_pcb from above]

Board: 4 copper layers, 24.0 x 60.0 mm, 12 parts (0 on the bottom side), 42 nets.

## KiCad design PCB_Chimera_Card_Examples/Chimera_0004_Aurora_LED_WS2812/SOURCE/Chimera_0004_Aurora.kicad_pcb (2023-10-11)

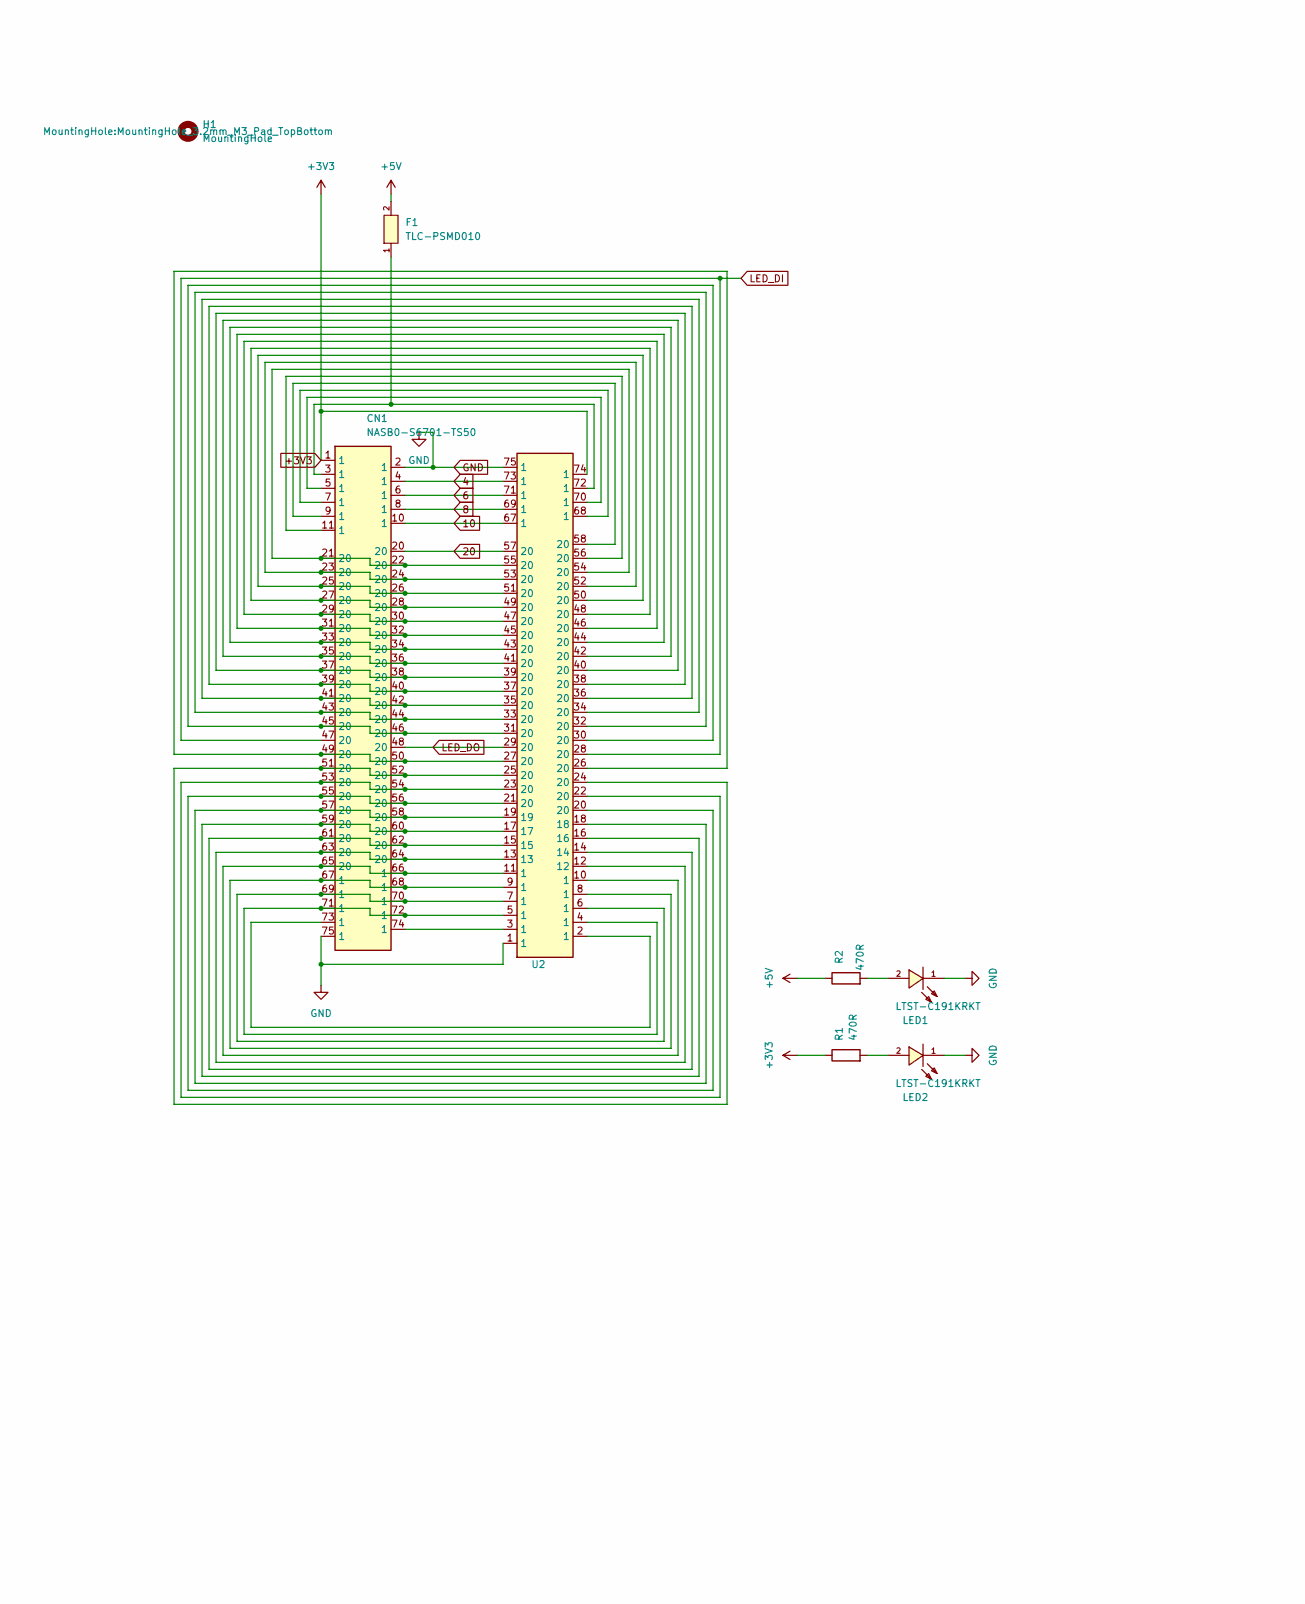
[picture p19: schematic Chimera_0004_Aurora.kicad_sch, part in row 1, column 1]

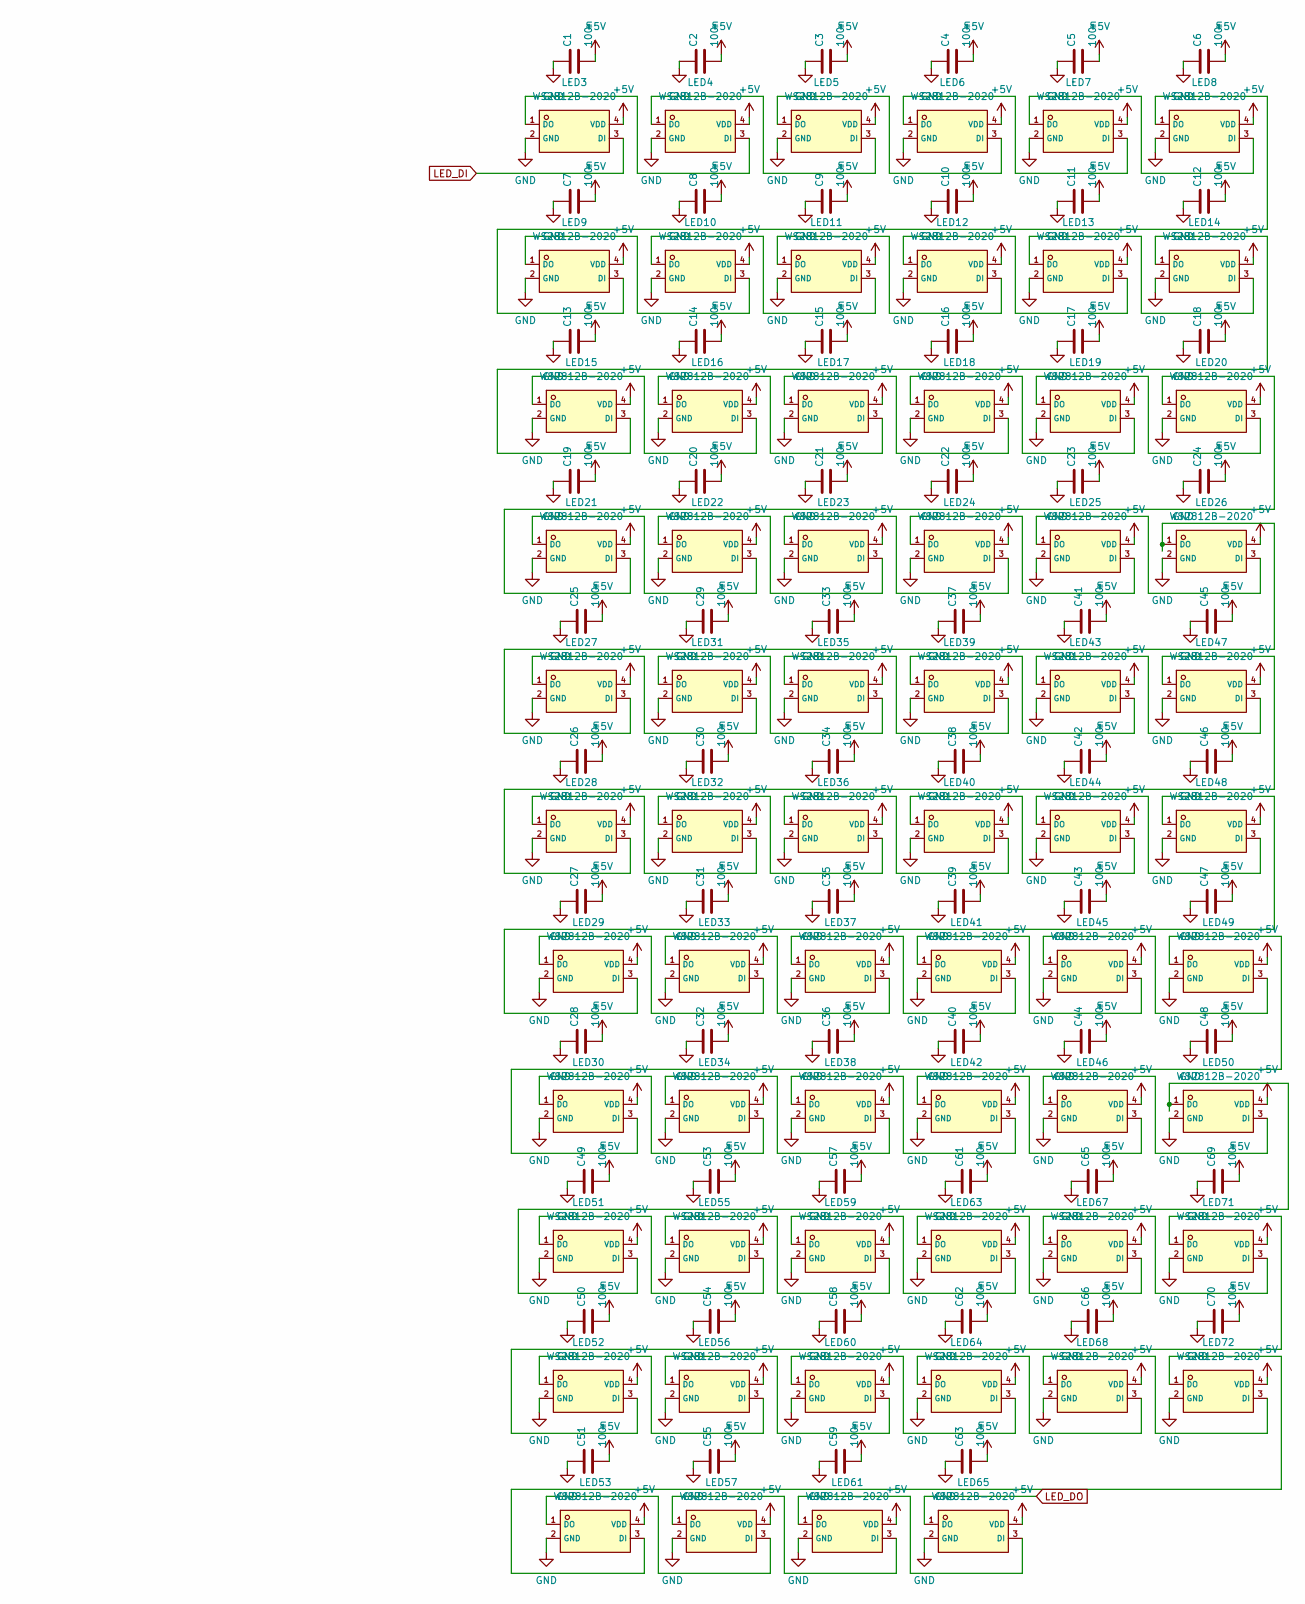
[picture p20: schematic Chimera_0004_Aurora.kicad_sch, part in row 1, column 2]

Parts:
C1, C2, C3, C4, C5, C6, C7, C8, C9, C10, C11, C12, C13, C14, C15, C16, C17, C18, C19, C20, C21, C22, C23, C24, C25, C26, C27, C28, C29, C30, C31, C32, C33, C34, C35, C36, C37, C38, C39, C40, C41, C42, C43, C44, C45, C46, C47, C48, C49, C50, C51, C53, C54, C55, C57, C58, C59, C61, C62, C63, C65, C66, C69, C70: 100n; C_0402_1005Metric
CN1: NASB0-S6701-TS50; CONN-SMD_67P-P0.50-V_NASB0-S6701-TS50; LCSC C367024
F1: TLC-PSMD010; F0805; LCSC C261939
H1: MountingHole; MountingHole_3.2mm_M3_Pad_TopBottom
LED1, LED2: LTST-C191KRKT; LED0603-RD; LCSC C125099
LED3, LED4, LED5, LED6, LED7, LED8, LED9, LED10, LED11, LED12, LED13, LED14, LED15, LED16, LED17, LED18, LED19, LED20, LED21, LED22, LED23, LED24, LED25, LED26, LED27, LED28, LED29, LED30, LED31, LED32, LED33, LED34, LED35, LED36, LED37, LED38, LED39, LED40, LED41, LED42, LED43, LED44, LED45, LED46, LED47, LED48, LED49, LED50, LED51, LED52, LED53, LED55, LED56, LED57, LED59, LED60, LED61, LED63, LED64, LED65, LED67, LED68, LED71, LED72: WS2812B-2020; LED-SMD_4P-L2.0-W2.0-TL_WS2812B-2020; LCSC C965555
R1, R2: 470R; R_0603_1608Metric
U2: NGFF_M

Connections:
4: CN1.4 (1), U2.73 (1)
6: CN1.6 (1), U2.71 (1)
8: CN1.8 (1), U2.69 (1)
10: CN1.10 (1), U2.67 (1)
20: CN1.20, U2.57 (20)
+3V3: CN1.1, R1.1, U2.74 (1)
+5V: C1.2, C2.2, C3.2, C4.2, C5.2, C6.2, C7.2, C8.2, C9.2, C10.2, C11.2, C12.2, C13.2, C14.2, C15.2, C16.2, C17.2, C18.2, C19.2, C20.2, C21.2, C22.2, C23.2, C24.2, C25.2, C26.2, C27.2, C28.2, C29.2, C30.2, C31.2, C32.2, C33.2, C34.2, C35.2, C36.2, C37.2, C38.2, C39.2, C40.2, C41.2, C42.2, C43.2, C44.2, C45.2, C46.2, C47.2, C48.2, C49.2, C50.2, C51.2, C53.2, C54.2, C55.2, C57.2, C58.2, C59.2, C61.2, C62.2, C63.2, C65.2, C66.2, C69.2, C70.2, F1.2, LED3.4 (VDD), LED4.4 (VDD), LED5.4 (VDD), LED6.4 (VDD), LED7.4 (VDD), LED8.4 (VDD), LED9.4 (VDD), LED10.4 (VDD), LED11.4 (VDD), LED12.4 (VDD), LED13.4 (VDD), LED14.4 (VDD), LED15.4 (VDD), LED16.4 (VDD), LED17.4 (VDD), LED18.4 (VDD), LED19.4 (VDD), LED20.4 (VDD), LED21.4 (VDD), LED22.4 (VDD), LED23.4 (VDD), LED24.4 (VDD), LED25.4 (VDD), LED26.4 (VDD), LED27.4 (VDD), LED28.4 (VDD), LED29.4 (VDD), LED30.4 (VDD), LED31.4 (VDD), LED32.4 (VDD), LED33.4 (VDD), LED34.4 (VDD), LED35.4 (VDD), LED36.4 (VDD), LED37.4 (VDD), LED38.4 (VDD), LED39.4 (VDD), LED40.4 (VDD), LED41.4 (VDD), LED42.4 (VDD), LED43.4 (VDD), LED44.4 (VDD), LED45.4 (VDD), LED46.4 (VDD), LED47.4 (VDD), LED48.4 (VDD), LED49.4 (VDD), LED50.4 (VDD), LED51.4 (VDD), LED52.4 (VDD), LED53.4 (VDD), LED55.4 (VDD), LED56.4 (VDD), LED57.4 (VDD), LED59.4 (VDD), LED60.4 (VDD), LED61.4 (VDD), LED63.4 (VDD), LED64.4 (VDD), LED65.4 (VDD), LED67.4 (VDD), LED68.4 (VDD), LED71.4 (VDD), LED72.4 (VDD), R2.1
GND: C1.1, C2.1, C3.1, C4.1, C5.1, C6.1, C7.1, C8.1, C9.1, C10.1, C11.1, C12.1, C13.1, C14.1, C15.1, C16.1, C17.1, C18.1, C19.1, C20.1, C21.1, C22.1, C23.1, C24.1, C25.1, C26.1, C27.1, C28.1, C29.1, C30.1, C31.1, C32.1, C33.1, C34.1, C35.1, C36.1, C37.1, C38.1, C39.1, C40.1, C41.1, C42.1, C43.1, C44.1, C45.1, C46.1, C47.1, C48.1, C49.1, C50.1, C51.1, C53.1, C54.1, C55.1, C57.1, C58.1, C59.1, C61.1, C62.1, C63.1, C65.1, C66.1, C69.1, C70.1, CN1.2 (1), CN1.75 (1), LED1.1 (-), LED2.1 (-), LED3.2 (GND), LED4.2 (GND), LED5.2 (GND), LED6.2 (GND), LED7.2 (GND), LED8.2 (GND), LED9.2 (GND), LED10.2 (GND), LED11.2 (GND), LED12.2 (GND), LED13.2 (GND), LED14.2 (GND), LED15.2 (GND), LED16.2 (GND), LED17.2 (GND), LED18.2 (GND), LED19.2 (GND), LED20.2 (GND), LED21.2 (GND), LED22.2 (GND), LED23.2 (GND), LED24.2 (GND), LED25.2 (GND), LED26.2 (GND), LED27.2 (GND), LED28.2 (GND), LED29.2 (GND), LED30.2 (GND), LED31.2 (GND), LED32.2 (GND), LED33.2 (GND), LED34.2 (GND), LED35.2 (GND), LED36.2 (GND), LED37.2 (GND), LED38.2 (GND), LED39.2 (GND), LED40.2 (GND), LED41.2 (GND), LED42.2 (GND), LED43.2 (GND), LED44.2 (GND), LED45.2 (GND), LED46.2 (GND), LED47.2 (GND), LED48.2 (GND), LED49.2 (GND), LED50.2 (GND), LED51.2 (GND), LED52.2 (GND), LED53.2 (GND), LED55.2 (GND), LED56.2 (GND), LED57.2 (GND), LED59.2 (GND), LED60.2 (GND), LED61.2 (GND), LED63.2 (GND), LED64.2 (GND), LED65.2 (GND), LED67.2 (GND), LED68.2 (GND), LED71.2 (GND), LED72.2 (GND), U2.1, U2.75 (1)
LED_DI: CN1.47 (20), LED3.3 (DI), U2.28 (20)
LED_DO: CN1.48 (20), LED65.1 (DO), U2.29 (20)
unnamed: CN1.3 (1), F1.1, U2.72 (1)
unnamed: CN1.5 (1), U2.70 (1)
unnamed: CN1.7 (1), U2.68 (1)
unnamed: CN1.9 (1), U2.58 (20)
unnamed: CN1.11 (1), U2.56 (20)
unnamed: CN1.65 (20), CN1.66 (1), U2.10 (1), U2.11 (1)
unnamed: CN1.67 (1), CN1.68 (1), U2.8 (1), U2.9 (1)
unnamed: CN1.69 (1), CN1.70 (1), U2.6 (1), U2.7 (1)
unnamed: CN1.71 (1), CN1.72 (1), U2.4 (1), U2.5 (1)
unnamed: CN1.73 (1), U2.2 (1)
unnamed: CN1.74 (1), U2.3 (1)
unnamed: CN1.21 (20), CN1.22 (20), U2.54 (20), U2.55 (20)
unnamed: CN1.23 (20), CN1.24 (20), U2.52 (20), U2.53 (20)
unnamed: CN1.25 (20), CN1.26 (20), U2.50 (20), U2.51 (20)
unnamed: CN1.27 (20), CN1.28 (20), U2.48 (20), U2.49 (20)
unnamed: CN1.29 (20), CN1.30 (20), U2.46 (20), U2.47 (20)
unnamed: CN1.31 (20), CN1.32 (20), U2.44 (20), U2.45 (20)
unnamed: CN1.33 (20), CN1.34 (20), U2.42 (20), U2.43 (20)
unnamed: CN1.35 (20), CN1.36 (20), U2.40 (20), U2.41 (20)
unnamed: CN1.37 (20), CN1.38 (20), U2.38 (20), U2.39 (20)
unnamed: CN1.39 (20), CN1.40 (20), U2.36 (20), U2.37 (20)
unnamed: CN1.41 (20), CN1.42 (20), U2.34 (20), U2.35 (20)
unnamed: CN1.43 (20), CN1.44 (20), U2.32 (20), U2.33 (20)
unnamed: CN1.45 (20), CN1.46 (20), U2.30 (20), U2.31 (20)
unnamed: CN1.49 (20), CN1.50 (20), U2.26 (20), U2.27 (20)
unnamed: CN1.51 (20), CN1.52 (20), U2.24 (20), U2.25 (20)
unnamed: CN1.53 (20), CN1.54 (20), U2.22 (20), U2.23 (20)
unnamed: CN1.55 (20), CN1.56 (20), U2.20, U2.21 (20)
unnamed: CN1.57 (20), CN1.58 (20), U2.18, U2.19
unnamed: CN1.59 (20), CN1.60 (20), U2.16, U2.17
unnamed: CN1.61 (20), CN1.62 (20), U2.14, U2.15
unnamed: CN1.63 (20), CN1.64 (20), U2.12, U2.13
unnamed: LED1.2 (+), R2.2
unnamed: LED2.2 (+), R1.2
unnamed: LED3.1 (DO), LED4.3 (DI)
unnamed: LED4.1 (DO), LED5.3 (DI)
unnamed: LED5.1 (DO), LED6.3 (DI)
unnamed: LED6.1 (DO), LED7.3 (DI)
unnamed: LED7.1 (DO), LED8.3 (DI)
unnamed: LED8.1 (DO), LED9.3 (DI)
unnamed: LED9.1 (DO), LED10.3 (DI)
unnamed: LED10.1 (DO), LED11.3 (DI)
unnamed: LED11.1 (DO), LED12.3 (DI)
unnamed: LED12.1 (DO), LED13.3 (DI)
unnamed: LED13.1 (DO), LED14.3 (DI)
unnamed: LED14.1 (DO), LED15.3 (DI)
unnamed: LED15.1 (DO), LED16.3 (DI)
unnamed: LED16.1 (DO), LED17.3 (DI)
unnamed: LED17.1 (DO), LED18.3 (DI)
unnamed: LED18.1 (DO), LED19.3 (DI)
unnamed: LED19.1 (DO), LED20.3 (DI)
unnamed: LED20.1 (DO), LED21.3 (DI)
unnamed: LED21.1 (DO), LED22.3 (DI)
unnamed: LED22.1 (DO), LED23.3 (DI)
unnamed: LED23.1 (DO), LED24.3 (DI)
unnamed: LED24.1 (DO), LED25.3 (DI)
unnamed: LED25.1 (DO), LED26.3 (DI)
unnamed: LED26.1 (DO), LED27.3 (DI)
unnamed: LED27.1 (DO), LED31.3 (DI)
unnamed: LED28.3 (DI), LED47.1 (DO)
unnamed: LED28.1 (DO), LED32.3 (DI)
unnamed: LED29.3 (DI), LED48.1 (DO)
unnamed: LED29.1 (DO), LED33.3 (DI)
unnamed: LED30.3 (DI), LED49.1 (DO)
unnamed: LED30.1 (DO), LED34.3 (DI)
unnamed: LED31.1 (DO), LED35.3 (DI)
unnamed: LED32.1 (DO), LED36.3 (DI)
unnamed: LED33.1 (DO), LED37.3 (DI)
unnamed: LED34.1 (DO), LED38.3 (DI)
unnamed: LED35.1 (DO), LED39.3 (DI)
unnamed: LED36.1 (DO), LED40.3 (DI)
unnamed: LED37.1 (DO), LED41.3 (DI)
unnamed: LED38.1 (DO), LED42.3 (DI)
unnamed: LED39.1 (DO), LED43.3 (DI)
unnamed: LED40.1 (DO), LED44.3 (DI)
unnamed: LED41.1 (DO), LED45.3 (DI)
unnamed: LED42.1 (DO), LED46.3 (DI)
unnamed: LED43.1 (DO), LED47.3 (DI)
unnamed: LED44.1 (DO), LED48.3 (DI)
unnamed: LED45.1 (DO), LED49.3 (DI)
unnamed: LED46.1 (DO), LED50.3 (DI)
unnamed: LED50.1 (DO), LED51.3 (DI)
unnamed: LED51.1 (DO), LED55.3 (DI)
unnamed: LED52.3 (DI), LED71.1 (DO)
unnamed: LED52.1 (DO), LED56.3 (DI)
unnamed: LED53.3 (DI), LED72.1 (DO)
unnamed: LED53.1 (DO), LED57.3 (DI)
unnamed: LED55.1 (DO), LED59.3 (DI)
unnamed: LED56.1 (DO), LED60.3 (DI)
unnamed: LED57.1 (DO), LED61.3 (DI)
unnamed: LED59.1 (DO), LED63.3 (DI)
unnamed: LED60.1 (DO), LED64.3 (DI)
unnamed: LED61.1 (DO), LED65.3 (DI)
unnamed: LED63.1 (DO), LED67.3 (DI)
unnamed: LED64.1 (DO), LED68.3 (DI)
unnamed: LED67.1 (DO), LED71.3 (DI)
unnamed: LED68.1 (DO), LED72.3 (DI)

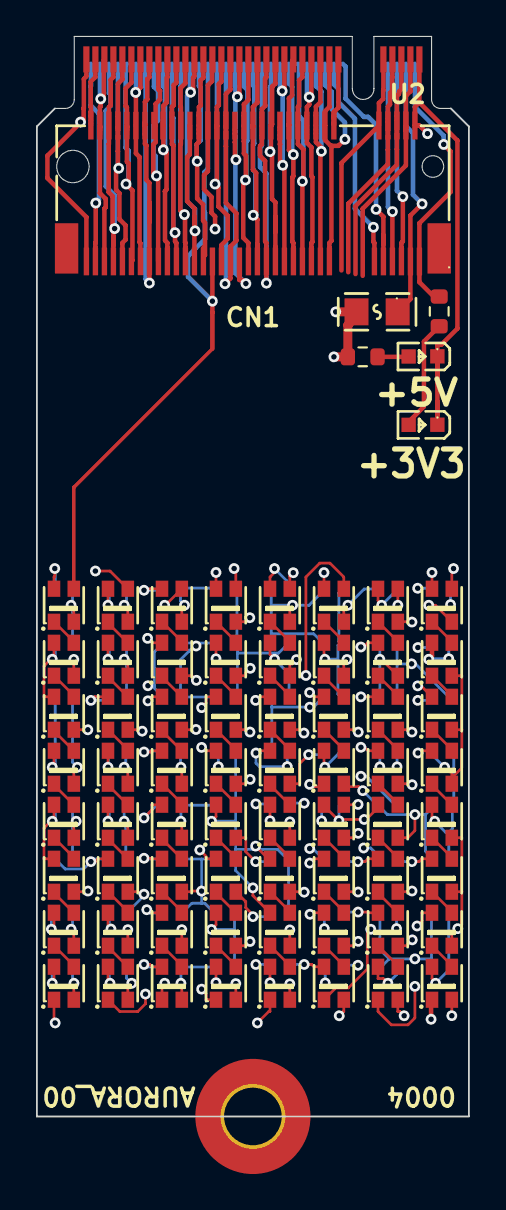
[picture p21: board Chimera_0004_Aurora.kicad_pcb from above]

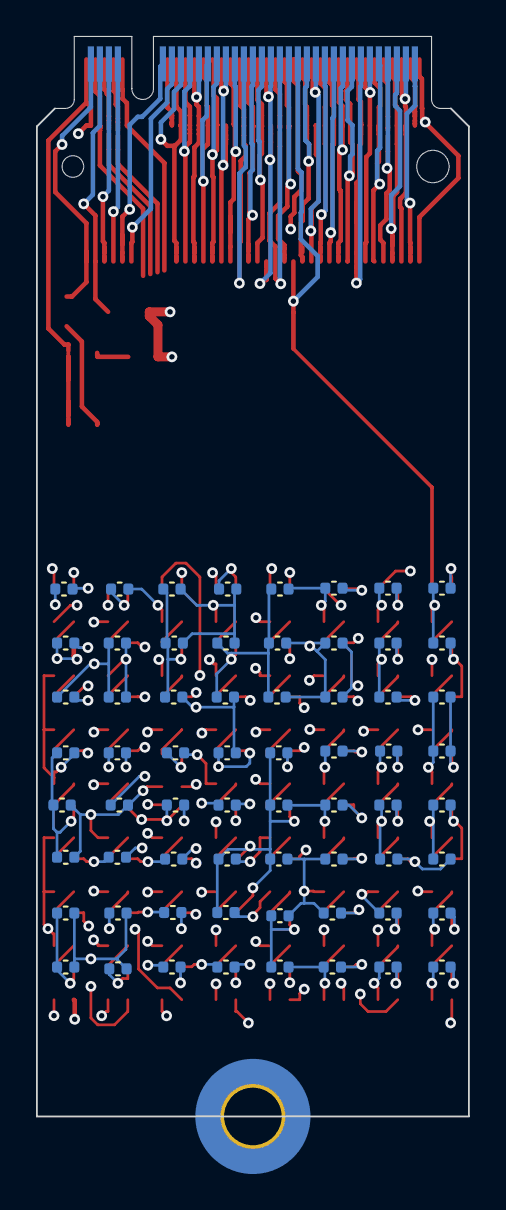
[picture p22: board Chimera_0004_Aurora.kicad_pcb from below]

Board: 4 copper layers, 24.0 x 60.0 mm, 136 parts (64 on the bottom side), 107 nets.

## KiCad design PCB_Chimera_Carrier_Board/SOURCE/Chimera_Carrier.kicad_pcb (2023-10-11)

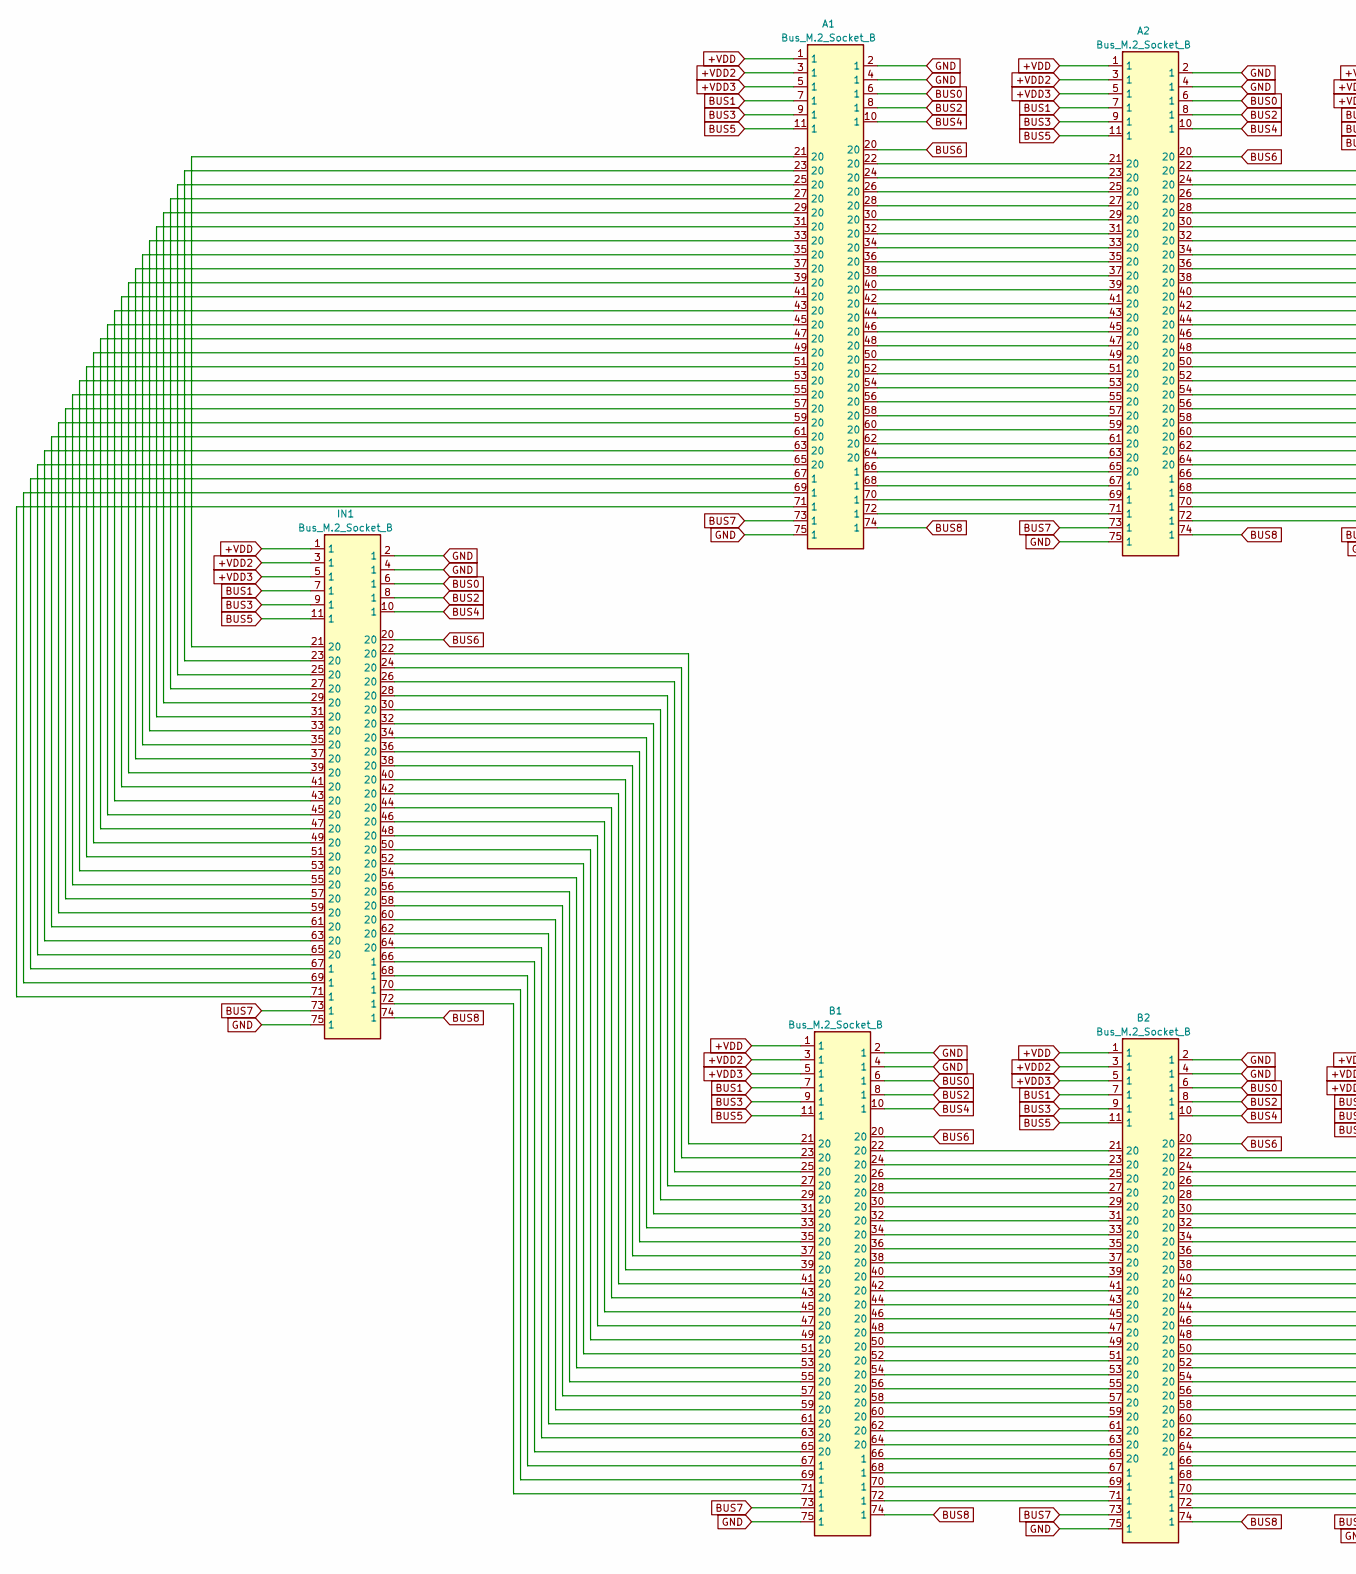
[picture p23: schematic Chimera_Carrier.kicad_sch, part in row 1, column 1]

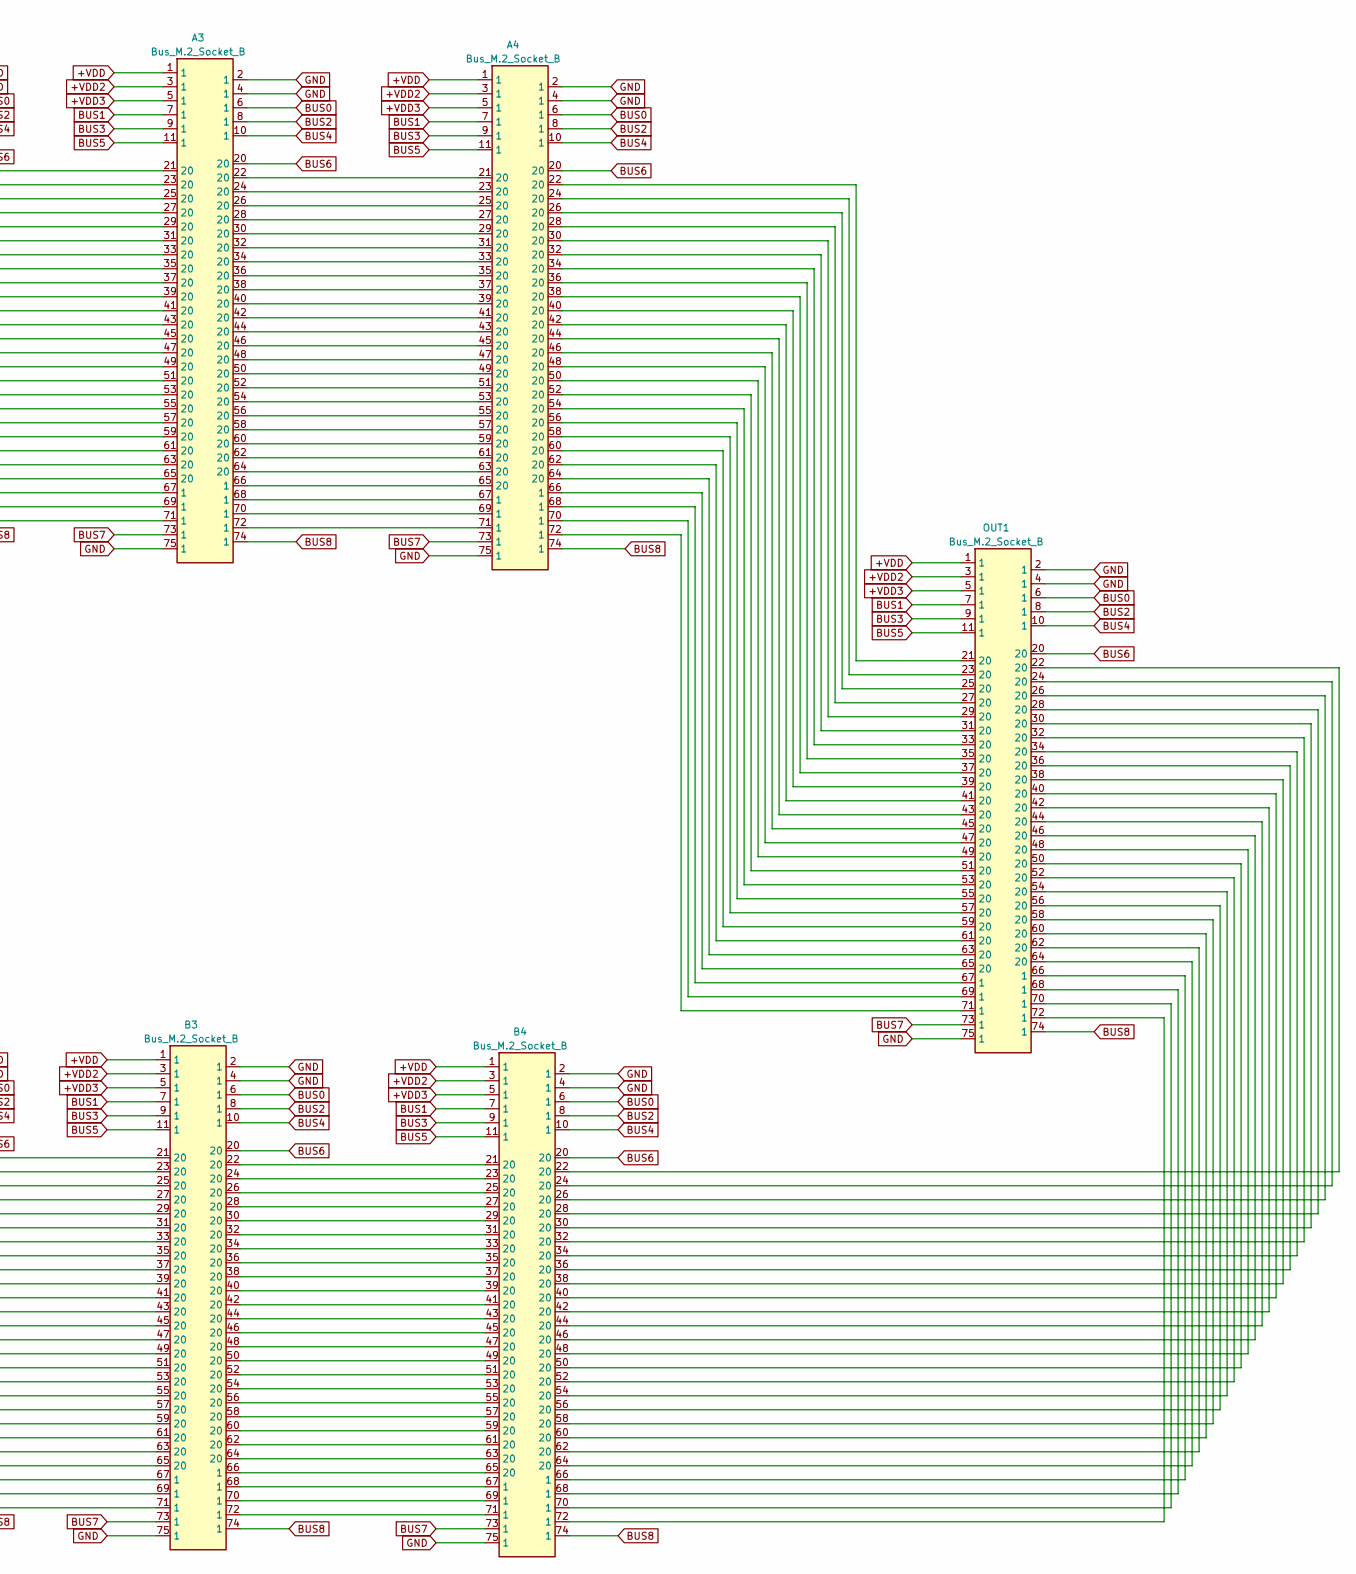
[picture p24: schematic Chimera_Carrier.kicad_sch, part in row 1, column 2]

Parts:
A1, A2, A3, A4: Bus_M.2_Socket_B; NGFF_B
B1, B2, B3, B4: Bus_M.2_Socket_B; NGFF_B
IN1: Bus_M.2_Socket_B; NGFF_B
OUT1: Bus_M.2_Socket_B; NGFF_B

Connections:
+VDD: A1.1, A2.1, A3.1, A4.1, B1.1, B2.1, B3.1, B4.1, IN1.1, OUT1.1
+VDD2: A1.3 (1), A2.3 (1), A3.3 (1), A4.3 (1), B1.3 (1), B2.3 (1), B3.3 (1), B4.3 (1), IN1.3 (1), OUT1.3 (1)
+VDD3: A1.5 (1), A2.5 (1), A3.5 (1), A4.5 (1), B1.5 (1), B2.5 (1), B3.5 (1), B4.5 (1), IN1.5 (1), OUT1.5 (1)
BUS0: A1.6 (1), A2.6 (1), A3.6 (1), A4.6 (1), B1.6 (1), B2.6 (1), B3.6 (1), B4.6 (1), IN1.6 (1), OUT1.6 (1)
BUS1: A1.7 (1), A2.7 (1), A3.7 (1), A4.7 (1), B1.7 (1), B2.7 (1), B3.7 (1), B4.7 (1), IN1.7 (1), OUT1.7 (1)
BUS2: A1.8 (1), A2.8 (1), A3.8 (1), A4.8 (1), B1.8 (1), B2.8 (1), B3.8 (1), B4.8 (1), IN1.8 (1), OUT1.8 (1)
BUS3: A1.9 (1), A2.9 (1), A3.9 (1), A4.9 (1), B1.9 (1), B2.9 (1), B3.9 (1), B4.9 (1), IN1.9 (1), OUT1.9 (1)
BUS4: A1.10 (1), A2.10 (1), A3.10 (1), A4.10 (1), B1.10 (1), B2.10 (1), B3.10 (1), B4.10 (1), IN1.10 (1), OUT1.10 (1)
BUS5: A1.11 (1), A2.11 (1), A3.11 (1), A4.11 (1), B1.11 (1), B2.11 (1), B3.11 (1), B4.11 (1), IN1.11 (1), OUT1.11 (1)
BUS7: A1.73 (1), A2.73 (1), A3.73 (1), A4.73 (1), B1.73 (1), B2.73 (1), B3.73 (1), B4.73 (1), IN1.73 (1), OUT1.73 (1)
BUS8: A1.74 (1), A2.74 (1), A3.74 (1), A4.74 (1), B1.74 (1), B2.74 (1), B3.74 (1), B4.74 (1), IN1.74 (1), OUT1.74 (1)
GND: A1.2 (1), A1.4 (1), A1.75 (1), A2.2 (1), A2.4 (1), A2.75 (1), A3.2 (1), A3.4 (1), A3.75 (1), A4.2 (1), A4.4 (1), A4.75 (1), B1.2 (1), B1.4 (1), B1.75 (1), B2.2 (1), B2.4 (1), B2.75 (1), B3.2 (1), B3.4 (1), B3.75 (1), B4.2 (1), B4.4 (1), B4.75 (1), IN1.2 (1), IN1.4 (1), IN1.75 (1), OUT1.2 (1), OUT1.4 (1), OUT1.75 (1)
unnamed: A1.66 (1), A2.65 (20)
unnamed: A1.67 (1), IN1.67 (1)
unnamed: A1.68 (1), A2.67 (1)
unnamed: A1.69 (1), IN1.69 (1)
unnamed: A1.70 (1), A2.69 (1)
unnamed: A1.71 (1), IN1.71 (1)
unnamed: A1.72 (1), A2.71 (1)
unnamed: A1.21 (20), IN1.21 (20)
unnamed: A1.22 (20), A2.21 (20)
unnamed: A1.23 (20), IN1.23 (20)
unnamed: A1.24 (20), A2.23 (20)
unnamed: A1.25 (20), IN1.25 (20)
unnamed: A1.26 (20), A2.25 (20)
unnamed: A1.27 (20), IN1.27 (20)
unnamed: A1.28 (20), A2.27 (20)
unnamed: A1.29 (20), IN1.29 (20)
unnamed: A1.30 (20), A2.29 (20)
unnamed: A1.31 (20), IN1.31 (20)
unnamed: A1.32 (20), A2.31 (20)
unnamed: A1.33 (20), IN1.33 (20)
unnamed: A1.34 (20), A2.33 (20)
unnamed: A1.35 (20), IN1.35 (20)
unnamed: A1.36 (20), A2.35 (20)
unnamed: A1.37 (20), IN1.37 (20)
unnamed: A1.38 (20), A2.37 (20)
unnamed: A1.39 (20), IN1.39 (20)
unnamed: A1.40 (20), A2.39 (20)
unnamed: A1.41 (20), IN1.41 (20)
unnamed: A1.42 (20), A2.41 (20)
unnamed: A1.43 (20), IN1.43 (20)
unnamed: A1.44 (20), A2.43 (20)
unnamed: A1.45 (20), IN1.45 (20)
unnamed: A1.46 (20), A2.45 (20)
unnamed: A1.47 (20), IN1.47 (20)
unnamed: A1.48 (20), A2.47 (20)
unnamed: A1.49 (20), IN1.49 (20)
unnamed: A1.50 (20), A2.49 (20)
unnamed: A1.51 (20), IN1.51 (20)
unnamed: A1.52 (20), A2.51 (20)
unnamed: A1.53 (20), IN1.53 (20)
unnamed: A1.54 (20), A2.53 (20)
unnamed: A1.55 (20), IN1.55 (20)
unnamed: A1.56 (20), A2.55 (20)
unnamed: A1.57 (20), IN1.57 (20)
unnamed: A1.58 (20), A2.57 (20)
unnamed: A1.59 (20), IN1.59 (20)
unnamed: A1.60 (20), A2.59 (20)
unnamed: A1.61 (20), IN1.61 (20)
unnamed: A1.62 (20), A2.61 (20)
unnamed: A1.63 (20), IN1.63 (20)
unnamed: A1.64 (20), A2.63 (20)
unnamed: A1.65 (20), IN1.65 (20)
unnamed: A2.66 (1), A3.65 (20)
unnamed: A2.68 (1), A3.67 (1)
unnamed: A2.70 (1), A3.69 (1)
unnamed: A2.72 (1), A3.71 (1)
unnamed: A2.22 (20), A3.21 (20)
unnamed: A2.24 (20), A3.23 (20)
unnamed: A2.26 (20), A3.25 (20)
unnamed: A2.28 (20), A3.27 (20)
unnamed: A2.30 (20), A3.29 (20)
unnamed: A2.32 (20), A3.31 (20)
unnamed: A2.34 (20), A3.33 (20)
unnamed: A2.36 (20), A3.35 (20)
unnamed: A2.38 (20), A3.37 (20)
unnamed: A2.40 (20), A3.39 (20)
unnamed: A2.42 (20), A3.41 (20)
unnamed: A2.44 (20), A3.43 (20)
unnamed: A2.46 (20), A3.45 (20)
unnamed: A2.48 (20), A3.47 (20)
unnamed: A2.50 (20), A3.49 (20)
unnamed: A2.52 (20), A3.51 (20)
unnamed: A2.54 (20), A3.53 (20)
unnamed: A2.56 (20), A3.55 (20)
unnamed: A2.58 (20), A3.57 (20)
unnamed: A2.60 (20), A3.59 (20)
unnamed: A2.62 (20), A3.61 (20)
unnamed: A2.64 (20), A3.63 (20)
unnamed: A3.66 (1), A4.65 (20)
unnamed: A3.68 (1), A4.67 (1)
unnamed: A3.70 (1), A4.69 (1)
unnamed: A3.72 (1), A4.71 (1)
unnamed: A3.22 (20), A4.21 (20)
unnamed: A3.24 (20), A4.23 (20)
unnamed: A3.26 (20), A4.25 (20)
unnamed: A3.28 (20), A4.27 (20)
unnamed: A3.30 (20), A4.29 (20)
unnamed: A3.32 (20), A4.31 (20)
unnamed: A3.34 (20), A4.33 (20)
unnamed: A3.36 (20), A4.35 (20)
unnamed: A3.38 (20), A4.37 (20)
unnamed: A3.40 (20), A4.39 (20)
unnamed: A3.42 (20), A4.41 (20)
unnamed: A3.44 (20), A4.43 (20)
unnamed: A3.46 (20), A4.45 (20)
unnamed: A3.48 (20), A4.47 (20)
unnamed: A3.50 (20), A4.49 (20)
unnamed: A3.52 (20), A4.51 (20)
unnamed: A3.54 (20), A4.53 (20)
unnamed: A3.56 (20), A4.55 (20)
unnamed: A3.58 (20), A4.57 (20)
unnamed: A3.60 (20), A4.59 (20)
unnamed: A3.62 (20), A4.61 (20)
unnamed: A3.64 (20), A4.63 (20)
unnamed: A4.66 (1), OUT1.65 (20)
unnamed: A4.68 (1), OUT1.67 (1)
unnamed: A4.70 (1), OUT1.69 (1)
unnamed: A4.72 (1), OUT1.71 (1)
unnamed: A4.22 (20), OUT1.21 (20)
unnamed: A4.24 (20), OUT1.23 (20)
unnamed: A4.26 (20), OUT1.25 (20)
unnamed: A4.28 (20), OUT1.27 (20)
unnamed: A4.30 (20), OUT1.29 (20)
unnamed: A4.32 (20), OUT1.31 (20)
unnamed: A4.34 (20), OUT1.33 (20)
unnamed: A4.36 (20), OUT1.35 (20)
unnamed: A4.38 (20), OUT1.37 (20)
unnamed: A4.40 (20), OUT1.39 (20)
unnamed: A4.42 (20), OUT1.41 (20)
unnamed: A4.44 (20), OUT1.43 (20)
unnamed: A4.46 (20), OUT1.45 (20)
unnamed: A4.48 (20), OUT1.47 (20)
unnamed: A4.50 (20), OUT1.49 (20)
unnamed: A4.52 (20), OUT1.51 (20)
unnamed: A4.54 (20), OUT1.53 (20)
unnamed: A4.56 (20), OUT1.55 (20)
unnamed: A4.58 (20), OUT1.57 (20)
unnamed: A4.60 (20), OUT1.59 (20)
unnamed: A4.62 (20), OUT1.61 (20)
unnamed: A4.64 (20), OUT1.63 (20)
unnamed: B1.66 (1), B2.65 (20)
unnamed: B1.67 (1), IN1.68 (1)
unnamed: B1.68 (1), B2.67 (1)
unnamed: B1.69 (1), IN1.70 (1)
unnamed: B1.70 (1), B2.69 (1)
unnamed: B1.71 (1), IN1.72 (1)
unnamed: B1.72 (1), B2.71 (1)
unnamed: B1.21 (20), IN1.22 (20)
unnamed: B1.22 (20), B2.21 (20)
unnamed: B1.23 (20), IN1.24 (20)
unnamed: B1.24 (20), B2.23 (20)
unnamed: B1.25 (20), IN1.26 (20)
unnamed: B1.26 (20), B2.25 (20)
unnamed: B1.27 (20), IN1.28 (20)
unnamed: B1.28 (20), B2.27 (20)
unnamed: B1.29 (20), IN1.30 (20)
unnamed: B1.30 (20), B2.29 (20)
unnamed: B1.31 (20), IN1.32 (20)
unnamed: B1.32 (20), B2.31 (20)
unnamed: B1.33 (20), IN1.34 (20)
unnamed: B1.34 (20), B2.33 (20)
unnamed: B1.35 (20), IN1.36 (20)
unnamed: B1.36 (20), B2.35 (20)
unnamed: B1.37 (20), IN1.38 (20)
unnamed: B1.38 (20), B2.37 (20)
unnamed: B1.39 (20), IN1.40 (20)
unnamed: B1.40 (20), B2.39 (20)
unnamed: B1.41 (20), IN1.42 (20)
unnamed: B1.42 (20), B2.41 (20)
unnamed: B1.43 (20), IN1.44 (20)
unnamed: B1.44 (20), B2.43 (20)
unnamed: B1.45 (20), IN1.46 (20)
unnamed: B1.46 (20), B2.45 (20)
unnamed: B1.47 (20), IN1.48 (20)
unnamed: B1.48 (20), B2.47 (20)
unnamed: B1.49 (20), IN1.50 (20)
unnamed: B1.50 (20), B2.49 (20)
unnamed: B1.51 (20), IN1.52 (20)
unnamed: B1.52 (20), B2.51 (20)
unnamed: B1.53 (20), IN1.54 (20)
unnamed: B1.54 (20), B2.53 (20)
unnamed: B1.55 (20), IN1.56 (20)
unnamed: B1.56 (20), B2.55 (20)
unnamed: B1.57 (20), IN1.58 (20)
unnamed: B1.58 (20), B2.57 (20)
unnamed: B1.59 (20), IN1.60 (20)
unnamed: B1.60 (20), B2.59 (20)
unnamed: B1.61 (20), IN1.62 (20)
unnamed: B1.62 (20), B2.61 (20)
unnamed: B1.63 (20), IN1.64 (20)
unnamed: B1.64 (20), B2.63 (20)
unnamed: B1.65 (20), IN1.66 (1)
unnamed: B2.66 (1), B3.65 (20)
unnamed: B2.68 (1), B3.67 (1)
unnamed: B2.70 (1), B3.69 (1)
unnamed: B2.22 (20), B3.21 (20)
unnamed: B2.24 (20), B3.23 (20)
unnamed: B2.26 (20), B3.25 (20)
unnamed: B2.28 (20), B3.27 (20)
unnamed: B2.30 (20), B3.29 (20)
unnamed: B2.32 (20), B3.31 (20)
unnamed: B2.34 (20), B3.33 (20)
unnamed: B2.36 (20), B3.35 (20)
unnamed: B2.38 (20), B3.37 (20)
unnamed: B2.40 (20), B3.39 (20)
unnamed: B2.42 (20), B3.41 (20)
unnamed: B2.44 (20), B3.43 (20)
unnamed: B2.46 (20), B3.45 (20)
unnamed: B2.48 (20), B3.47 (20)
unnamed: B2.50 (20), B3.49 (20)
unnamed: B2.52 (20), B3.51 (20)
unnamed: B2.54 (20), B3.53 (20)
unnamed: B2.56 (20), B3.55 (20)
unnamed: B2.58 (20), B3.57 (20)
unnamed: B2.60 (20), B3.59 (20)
unnamed: B2.62 (20), B3.61 (20)
unnamed: B2.64 (20), B3.63 (20)
unnamed: B3.66 (1), B4.65 (20)
unnamed: B3.68 (1), B4.67 (1)
unnamed: B3.70 (1), B4.69 (1)
unnamed: B3.72 (1), B4.71 (1)
unnamed: B3.22 (20), B4.21 (20)
unnamed: B3.24 (20), B4.23 (20)
unnamed: B3.26 (20), B4.25 (20)
unnamed: B3.28 (20), B4.27 (20)
unnamed: B3.30 (20), B4.29 (20)
unnamed: B3.32 (20), B4.31 (20)
unnamed: B3.34 (20), B4.33 (20)
unnamed: B3.36 (20), B4.35 (20)
unnamed: B3.38 (20), B4.37 (20)
unnamed: B3.40 (20), B4.39 (20)
unnamed: B3.42 (20), B4.41 (20)
unnamed: B3.44 (20), B4.43 (20)
unnamed: B3.46 (20), B4.45 (20)
unnamed: B3.48 (20), B4.47 (20)
unnamed: B3.50 (20), B4.49 (20)
unnamed: B3.52 (20), B4.51 (20)
unnamed: B3.54 (20), B4.53 (20)
unnamed: B3.56 (20), B4.55 (20)
unnamed: B3.58 (20), B4.57 (20)
unnamed: B3.60 (20), B4.59 (20)
unnamed: B3.62 (20), B4.61 (20)
unnamed: B3.64 (20), B4.63 (20)
unnamed: B4.66 (1), OUT1.66 (1)
unnamed: B4.68 (1), OUT1.68 (1)
unnamed: B4.70 (1), OUT1.70 (1)
unnamed: B4.72 (1), OUT1.72 (1)
unnamed: B4.22 (20), OUT1.22 (20)
unnamed: B4.24 (20), OUT1.24 (20)
unnamed: B4.26 (20), OUT1.26 (20)
unnamed: B4.28 (20), OUT1.28 (20)
unnamed: B4.30 (20), OUT1.30 (20)
unnamed: B4.32 (20), OUT1.32 (20)
unnamed: B4.34 (20), OUT1.34 (20)
unnamed: B4.36 (20), OUT1.36 (20)
unnamed: B4.38 (20), OUT1.38 (20)
unnamed: B4.40 (20), OUT1.40 (20)
unnamed: B4.42 (20), OUT1.42 (20)
unnamed: B4.44 (20), OUT1.44 (20)
unnamed: B4.46 (20), OUT1.46 (20)
unnamed: B4.48 (20), OUT1.48 (20)
unnamed: B4.50 (20), OUT1.50 (20)
unnamed: B4.52 (20), OUT1.52 (20)
unnamed: B4.54 (20), OUT1.54 (20)
unnamed: B4.56 (20), OUT1.56 (20)
unnamed: B4.58 (20), OUT1.58 (20)
unnamed: B4.60 (20), OUT1.60 (20)
unnamed: B4.62 (20), OUT1.62 (20)
unnamed: B4.64 (20), OUT1.64 (20)

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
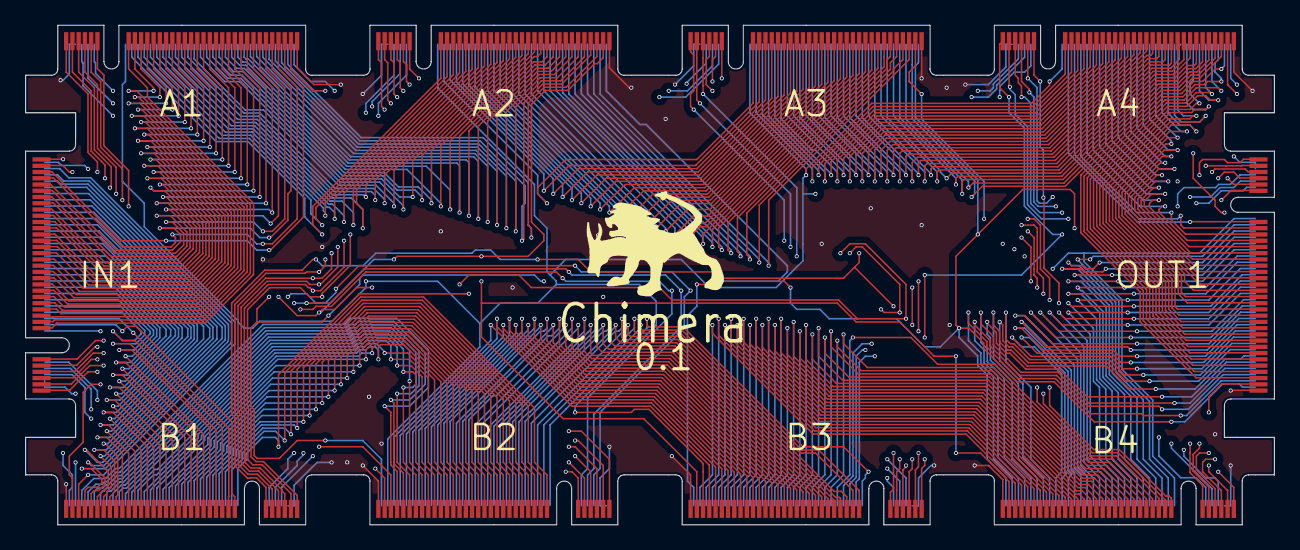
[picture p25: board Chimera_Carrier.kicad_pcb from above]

Board: 4 copper layers, 100.0 x 40.0 mm, 11 parts (0 on the bottom side), 273 nets.

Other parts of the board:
Chimera: LOGO

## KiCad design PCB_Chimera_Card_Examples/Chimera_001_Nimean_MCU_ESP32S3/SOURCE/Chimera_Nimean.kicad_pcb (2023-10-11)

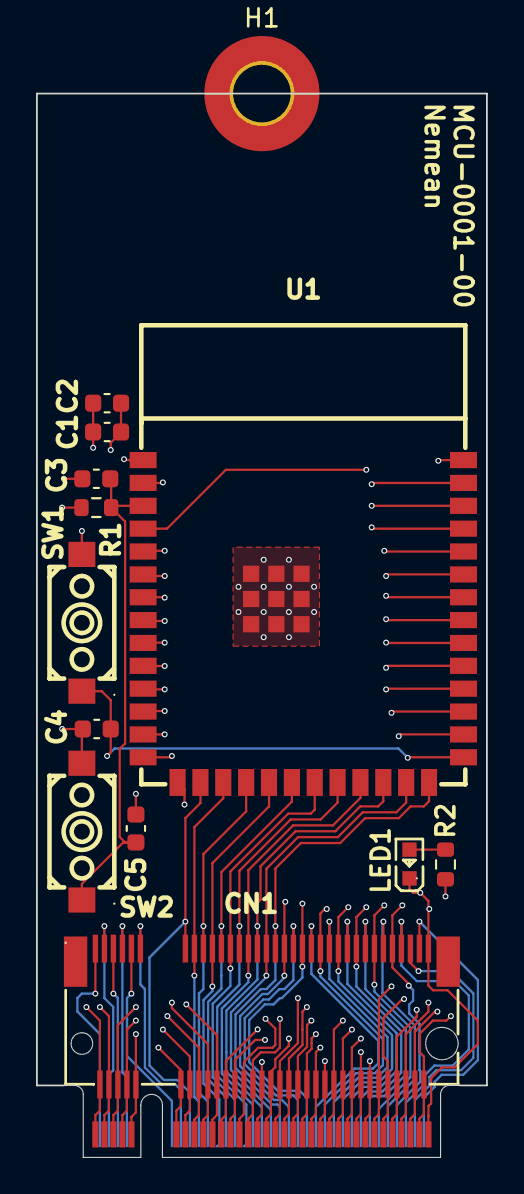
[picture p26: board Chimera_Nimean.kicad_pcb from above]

Board: 4 copper layers, 25.0 x 59.1 mm, 14 parts (0 on the bottom side), 69 nets.

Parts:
C1: 22u; C_0603_1608Metric
C2: 100n; C_0603_1608Metric
C3: 1u; C_0603_1608Metric
C4, C5: 0.1u; C_0603_1608Metric
CN1: NASB0-S6701-TS50; CONN-SMD_67P-P0.50-V_NASB0-S6701-TS50
H1: MountingHole; MountingHole_3.2mm_M3_Pad_TopBottom
LED1: LTST-C191KRKT; LED0603-RD
R1: 10k; R_0603_1608Metric
R2: 1k; R_0603_1608Metric
SW1, SW2: K2-1107ST-A4SW-06; KEY-SMD_L6.2-W3.6-LS8.0
U1: ESP32-S3-WROOM-1-N8; WIFIM-SMD_ESP32-S3-WROOM-1-N8
U2: NGFF_M

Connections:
+3V3: C1.1, C2.1, CN1.1, R1.1, R2.1, U1.2 (3V3), U2.74 (1)
BOOT: C4.1, CN1.67 (1), SW1.1, U1.27 (IO0), U2.8 (1)
EN: C3.1, C5.1, R1.2, SW2.1, U1.3 (EN)
GND: C1.2, C2.2, C3.2, C4.2, C5.2, CN1.75 (1), LED1.1 (-), SW1.2, SW2.2, U1.1 (GND), U1.40 (GND), U1.41 (EP), U2.1
IO1: CN1.43 (20), U1.39 (IO1), U2.32 (20)
IO2: CN1.45 (20), U1.38 (IO2), U2.30 (20)
IO3: CN1.11 (1), U1.15 (IO3), U2.56 (20)
IO4: CN1.50 (20), U1.4 (IO4), U2.27 (20)
IO5: CN1.48 (20), U1.5 (IO5), U2.29 (20)
IO6: CN1.46 (20), U1.6 (IO6), U2.31 (20)
IO7: CN1.44 (20), U1.7 (IO7), U2.33 (20)
IO8: CN1.34 (20), U1.12 (IO8), U2.43 (20)
IO9: CN1.23 (20), U1.17 (IO9), U2.52 (20)
IO10: CN1.25 (20), U1.18 (IO10), U2.50 (20)
IO11: CN1.27 (20), U1.19 (IO11), U2.48 (20)
IO12: CN1.29 (20), U1.20 (IO12), U2.46 (20)
IO13: CN1.31 (20), U1.21 (IO13), U2.44 (20)
IO14: CN1.33 (20), U1.22 (IO14), U2.42 (20)
IO15: CN1.42 (20), U1.8 (IO15), U2.35 (20)
IO16: CN1.40 (20), U1.9 (IO16), U2.37 (20)
IO17: CN1.38 (20), U1.10 (IO17), U2.39 (20)
IO18: CN1.36 (20), U1.11 (IO18), U2.41 (20)
IO19: CN1.32 (20), U1.13 (IO19), U2.45 (20)
IO20: CN1.30 (20), U1.14 (IO20), U2.47 (20)
IO21: CN1.35 (20), U1.23 (IO21), U2.40 (20)
IO35: CN1.65 (20), U1.28 (IO35), U2.10 (1)
IO36: CN1.63 (20), U1.29 (IO36), U2.12
IO37: CN1.61 (20), U1.30 (IO37), U2.14
IO38: CN1.59 (20), U1.31 (IO38), U2.16
IO39: CN1.57 (20), U1.32 (IO39), U2.18
IO40: CN1.55 (20), U1.33 (IO40), U2.20
IO41: CN1.53 (20), U1.34 (IO41), U2.22 (20)
IO42: CN1.51 (20), U1.35 (IO42), U2.24 (20)
IO45: CN1.41 (20), U1.26 (IO45), U2.34 (20)
IO46: CN1.21 (20), U1.16 (IO46), U2.54 (20)
IO47: CN1.37 (20), U1.24 (IO47), U2.38 (20)
IO48: CN1.39 (20), U1.25 (IO48), U2.36 (20)
unnamed: CN1.2 (1), U2.75 (1)
unnamed: CN1.3 (1), U2.72 (1)
unnamed: CN1.4 (1), U2.73 (1)
unnamed: CN1.5 (1), U2.70 (1)
unnamed: CN1.6 (1), U2.71 (1)
unnamed: CN1.7 (1), U2.68 (1)
unnamed: CN1.8 (1), U2.69 (1)
unnamed: CN1.9 (1), U2.58 (20)
unnamed: CN1.10 (1), U2.67 (1)
unnamed: CN1.66 (1), U2.11 (1)
unnamed: CN1.68 (1), U2.9 (1)
unnamed: CN1.69 (1), U2.6 (1)
unnamed: CN1.70 (1), U2.7 (1)
unnamed: CN1.71 (1), U2.4 (1)
unnamed: CN1.72 (1), U2.5 (1)
unnamed: CN1.73 (1), U2.2 (1)
unnamed: CN1.74 (1), U2.3 (1)
unnamed: CN1.22 (20), U2.55 (20)
unnamed: CN1.24 (20), U2.53 (20)
unnamed: CN1.26 (20), U2.51 (20)
unnamed: CN1.28 (20), U2.49 (20)
unnamed: CN1.52 (20), U2.25 (20)
unnamed: CN1.54 (20), U2.23 (20)
unnamed: CN1.56 (20), U2.21 (20)
unnamed: CN1.58 (20), U2.19
unnamed: CN1.60 (20), U2.17
unnamed: CN1.62 (20), U2.15
unnamed: CN1.64 (20), U2.13
unnamed: CN1.20, U2.57 (20)
unnamed: LED1.2 (+), R2.2
RXD0: CN1.49 (20), U1.36 (RXD0), U2.26 (20)
TXD0: CN1.47 (20), U1.37 (TXD0), U2.28 (20)

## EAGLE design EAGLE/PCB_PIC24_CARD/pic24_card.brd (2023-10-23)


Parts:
M1: MOUNTING_3M_3.2MM
R8: 470R; R0402_NIBE
STATUS: LED_YELLOW; R0603
X1: CONN_SMD_67P-P0.5-V_NASB0-S6701-TS50
X2: M.2_MKEY_FINGERS

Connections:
+3V3: X1.P$1 (1), X2.74; also elsewhere on the board
A: X1.P$9 (9), X2.58; also elsewhere on the board
AN2: X1.P$70 (70), X2.7; also elsewhere on the board
AN3: X1.P$69 (69), X2.6; also elsewhere on the board
AN4: X1.P$67 (67), X2.8; also elsewhere on the board
AN5: X1.P$68 (68), X2.9; also elsewhere on the board
AN6: X1.P$71 (71), X2.4; also elsewhere on the board
AN7: X1.P$72 (72), X2.5; also elsewhere on the board
AN8: X1.P$60 (60), X2.17; also elsewhere on the board
AN9: X1.P$49 (49), X2.26; also elsewhere on the board
AN10: X1.P$47 (47), X2.28; also elsewhere on the board
AN11: X1.P$58 (58), X2.19; also elsewhere on the board
AN12: X1.P$45 (45), X2.30; also elsewhere on the board
AN13: X1.P$43 (43), X2.32; also elsewhere on the board
AN14: X1.P$56 (56), X2.21; also elsewhere on the board
AN15: X1.P$50 (50), X2.27; also elsewhere on the board
AN16: X1.P$57 (57), X2.18; also elsewhere on the board
AN17: X1.P$64 (64), X2.13; also elsewhere on the board
AN18: X1.P$59 (59), X2.16; also elsewhere on the board
AN19: X1.P$61 (61), X2.14; also elsewhere on the board
AN20: X1.P$66 (66), X2.11; also elsewhere on the board
AN21: X1.P$65 (65), X2.10; also elsewhere on the board
AN22: X1.P$52 (52), X2.25; also elsewhere on the board
AN23: X1.P$54 (54), X2.23; also elsewhere on the board
B: X1.P$11 (11), X2.56; also elsewhere on the board
GND: STATUS.1 (2), X1.P$2 (2), X1.P$4 (4), X1.P$75 (75), X2.1, X2.73, X2.75; also elsewhere on the board
LED_STATUS: R8.1; also elsewhere on the board
unnamed: R8.2, STATUS.2 (1)
unnamed: X1.P$7 (7), X2.68
unnamed: X1.P$5 (5), X2.70
unnamed: X1.P$3 (3), X2.72
unnamed: X1.P$6 (6), X2.71
unnamed: X1.P$8 (8), X2.69
unnamed: X1.P$10 (10), X2.67
unnamed: X1.P$20 (20), X2.57
RC13: X1.P$22 (22), X2.55; also elsewhere on the board
RP2: X1.P$28 (28), X2.49; also elsewhere on the board
RP3: X1.P$32 (32), X2.45; also elsewhere on the board
RP4: X1.P$30 (30), X2.47; also elsewhere on the board
RP5: X1.P$37 (37), X2.38; also elsewhere on the board
RP10: X1.P$35 (35), X2.40; also elsewhere on the board
RP11: X1.P$36 (36), X2.41; also elsewhere on the board
RP12: X1.P$34 (34), X2.43; also elsewhere on the board
RP15: X1.P$27 (27), X2.48; also elsewhere on the board
RP16: X1.P$31 (31), X2.44; also elsewhere on the board
RP17: X1.P$33 (33), X2.42; also elsewhere on the board
RP20: X1.P$21 (21), X2.54; also elsewhere on the board
RP22: X1.P$44 (44), X2.33; also elsewhere on the board
RP23: X1.P$42 (42), X2.35; also elsewhere on the board
RP24: X1.P$40 (40), X2.37; also elsewhere on the board
RP25: X1.P$48 (48), X2.29; also elsewhere on the board
RP30: X1.P$29 (29), X2.46; also elsewhere on the board
RP32: X1.P$23 (23), X2.52; also elsewhere on the board
RP33: X1.P$25 (25), X2.50; also elsewhere on the board
RP34: X1.P$51 (51), X2.24; also elsewhere on the board
RP35: X1.P$73 (73), X2.2; also elsewhere on the board
RP36: X1.P$74 (74), X2.3; also elsewhere on the board
RPI37: X1.P$38 (38), X2.39; also elsewhere on the board
RPI38: X1.P$53 (53), X2.22; also elsewhere on the board
RPI39: X1.P$62 (62), X2.15; also elsewhere on the board
RPI40: X1.P$55 (55), X2.20; also elsewhere on the board
RPI42: X1.P$46 (46), X2.31; also elsewhere on the board
RPI43: X1.P$39 (39), X2.36; also elsewhere on the board
RPI45: X1.P$41 (41), X2.34; also elsewhere on the board
RPI47: X1.P$63 (63), X2.12; also elsewhere on the board
RPI49: X1.P$26 (26), X2.51; also elsewhere on the board
RPI50: X1.P$24 (24), X2.53; also elsewhere on the board


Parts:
C1, C5: 16p; C0402_NIBE
C2, C3, C4, C6, C7, C8, C9, C11: 100n; C0402_NIBE
C10: 10u; C0805
IC1: PIC24FJ256GL410
IC2: XR3072XID-F; SOIC8
R1, R4, R7: 10k; R0402_NIBE
R2: 820R; R0402_NIBE
R3: 470R; R0402_NIBE
R5, R6: 3k3; R0402_NIBE
X3: 5-PIN_2.54_HEADER; 2.54MM_5HOLE_TH
Y1: FA238-12MHZ; FA238

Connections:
+3V3: C3.1, C4.1, C6.1, C7.1, C8.1, C9.1, C10.1, C11.1, IC1.2 (VDD1), IC1.16 (VDD2), IC1.30 (AVDD), IC1.37 (V_USB), IC1.46 (VDD3), IC1.62 (VDD4), IC1.85 (VCAP), IC2.8 (VCC), R1.2, R4.2, R5.2, X3.2; also elsewhere on the board
A: IC2.6 (A), R5.1; also elsewhere on the board
AN2: IC1.23 (AN2/RP13/RB2); also elsewhere on the board
AN3: IC1.22 (AN3/RB3); also elsewhere on the board
AN4: IC1.21 (AN4/RP28/RB4); also elsewhere on the board
AN5: IC1.20 (AN5/RP18/RB5); also elsewhere on the board
AN6: IC1.26 (AN6/RP6/RB6); also elsewhere on the board
AN7: IC1.27 (AN7/RP7/RB7); also elsewhere on the board
AN8: IC1.32 (AN8/RP8/RB8); also elsewhere on the board
AN9: IC1.33 (AN9/RP9/RB9); also elsewhere on the board
AN10: IC1.34 (AN10/RPI44/RB10); also elsewhere on the board
AN11: IC1.35 (AN11RB11); also elsewhere on the board
AN12: IC1.41 (AN12/RB12); also elsewhere on the board
AN13: IC1.42 (AN13/RB13); also elsewhere on the board
AN14: IC1.43 (AN14/RP14/RB14); also elsewhere on the board
AN15: IC1.44 (AN15/RP29/RB15); also elsewhere on the board
AN16: IC1.9 (AN16/RPI41/RC4); also elsewhere on the board
AN17: IC1.10 (AN17/RP21/RG6); also elsewhere on the board
AN18: IC1.11 (AN18/RP6/RG7); also elsewhere on the board
AN19: IC1.12 (AN19/RP19/RG8); also elsewhere on the board
AN20: IC1.14 (AN20/RP27/RG9); also elsewhere on the board
AN21: IC1.19 (AN21/RPI48/RE9); also elsewhere on the board
AN22: IC1.91 (AN22/RA6); also elsewhere on the board
AN23: IC1.92 (AN23/RA7); also elsewhere on the board
B: IC2.7 (B), R6.2; also elsewhere on the board
DE: IC1.38 (RA1), IC2.3 (DE), R7.2
GND: C1.2, C2.2, C3.2, C4.2, C5.2, C6.2, C7.2, C8.2, C9.2, C10.2, C11.2, IC1.15 (VSS1), IC1.31 (AVSS), IC1.36 (VSS2), IC1.45 (VSS3), IC1.65 (VSS4), IC1.75 (VSS5), IC2.2 (!RE), IC2.5 (GND), R6.1, R7.1, X3.3, Y1.2, Y1.4 (2); also elsewhere on the board
LED_STATUS: IC1.54 (RF7); also elsewhere on the board
MCLR: IC1.13 (MCLR), R3.1, X3.1
unnamed: C2.1, R1.1, R3.2
unnamed: C5.1, R2.1, Y1.3
OSC_IN: C1.1, IC1.63 (OSC_IN), Y1.1
OSC_OUT: IC1.64 (OSC_OUT), R2.2
PGC: IC1.24 (PGC), X3.5
PGD: IC1.25 (PGD), X3.4
RC13: IC1.73 (RC13); also elsewhere on the board
RP2: IC1.68 (RP2/RD8); also elsewhere on the board
RP3: IC1.70 (RP3/RD10); also elsewhere on the board
RP4: IC1.69 (RP4/RD9); also elsewhere on the board
RP5: IC1.48 (RP5/RD15); also elsewhere on the board
RP10: IC1.49 (RP10/RF4); also elsewhere on the board
RP11: IC1.72 (RP11/RD0); also elsewhere on the board
RP12: IC1.71 (RP12/RD11); also elsewhere on the board
RP15: IC1.53 (RP15/RF8); also elsewhere on the board
RP16: IC1.51 (RP16/RF3); also elsewhere on the board
RP17: IC1.50 (RP17/RF5); also elsewhere on the board
RP20: IC1.82 (RP20/SD03/RD5); also elsewhere on the board
RP22: IC1.78 (RP22/RD3); also elsewhere on the board
RP23: IC1.77 (RP23/RD2); also elsewhere on the board
RP24: IC1.76 (RP24/RD1); also elsewhere on the board
RP25: IC1.81 (RP25/SDI3/RD4); also elsewhere on the board
RP30: IC1.52 (RP30/RF2); also elsewhere on the board
RP32: IC1.83 (RP32/RD6); also elsewhere on the board
RP33: IC1.84 (RP33/RD7); also elsewhere on the board
RP34: IC1.3 (RP34/RE5); also elsewhere on the board
RP35: IC1.4 (RP35/SCL3/RE6); also elsewhere on the board
RP36: IC1.5 (RP36/SDA3/RE7); also elsewhere on the board
RPI37: IC1.74 (RPI37/RC14); also elsewhere on the board
RPI38: IC1.6 (RPI38/RC1); also elsewhere on the board
RPI39: IC1.7 (RPI39/RC2); also elsewhere on the board
RPI40: IC1.8 (RPI40/RC3); also elsewhere on the board
RPI42: IC1.79 (RPI42/RD12); also elsewhere on the board
RPI43: IC1.47 (RPI43/RD14); also elsewhere on the board
RPI45: IC1.88 (RPI45/RF1); also elsewhere on the board
RPI47: IC1.18 (RPI47/RE8); also elsewhere on the board
RPI49: IC1.67 (RPI49/RA15); also elsewhere on the board
RPI50: IC1.66 (RPI50/RA14); also elsewhere on the board
RX_485: IC1.40 (RPI46/RF12), IC2.1 (RO)
TX_485: IC1.39 (RP31/RF13), IC2.4 (DI), R4.1


Board: 4 copper layers, 24.0 x 60.0 mm, 27 parts (0 on the bottom side), 77 nets.

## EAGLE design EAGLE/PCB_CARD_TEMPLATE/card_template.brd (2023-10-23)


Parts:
LED1: LED_GREEN; R0603
M1: MOUNTING_3M_3.2MM
R2: 470R; R0603
X1: CONN_SMD_67P-P0.5-V_NASB0-S6701-TS50
X2: M.2_MKEY_FINGERS

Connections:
+3V3: R2.1, X1.P$1 (1), X2.74
+5V: X1.P$3 (3), X2.72
GND: LED1.2, X1.P$2 (2), X1.P$4 (4), X1.P$75 (75), X2.1, X2.73, X2.75
unnamed: X1.P$23 (23), X1.P$24 (24), X2.52, X2.53
unnamed: X1.P$25 (25), X1.P$26 (26), X2.50, X2.51
unnamed: X1.P$73 (73), X1.P$74 (74), X2.2, X2.3
unnamed: X1.P$71 (71), X1.P$72 (72), X2.4, X2.5
unnamed: X1.P$69 (69), X1.P$70 (70), X2.6, X2.7
unnamed: X1.P$67 (67), X1.P$68 (68), X2.8, X2.9
unnamed: X1.P$65 (65), X1.P$66 (66), X2.10, X2.11
unnamed: X1.P$63 (63), X1.P$64 (64), X2.12, X2.13
unnamed: X1.P$61 (61), X1.P$62 (62), X2.14, X2.15
unnamed: X1.P$59 (59), X1.P$60 (60), X2.16, X2.17
unnamed: X1.P$57 (57), X1.P$58 (58), X2.18, X2.19
unnamed: X1.P$55 (55), X1.P$56 (56), X2.20, X2.21
unnamed: X1.P$53 (53), X1.P$54 (54), X2.22, X2.23
unnamed: X1.P$51 (51), X1.P$52 (52), X2.24, X2.25
unnamed: X1.P$21 (21), X1.P$22 (22), X2.54, X2.55
unnamed: X1.P$27 (27), X1.P$28 (28), X2.48, X2.49
unnamed: X1.P$29 (29), X1.P$30 (30), X2.46, X2.47
unnamed: X1.P$31 (31), X1.P$32 (32), X2.44, X2.45
unnamed: X1.P$33 (33), X1.P$34 (34), X2.42, X2.43
unnamed: X1.P$35 (35), X1.P$36 (36), X2.40, X2.41
unnamed: X1.P$37 (37), X1.P$38 (38), X2.38, X2.39
unnamed: X1.P$39 (39), X1.P$40 (40), X2.36, X2.37
unnamed: X1.P$41 (41), X1.P$42 (42), X2.34, X2.35
unnamed: X1.P$43 (43), X1.P$44 (44), X2.32, X2.33
unnamed: X1.P$45 (45), X1.P$46 (46), X2.30, X2.31
unnamed: X1.P$47 (47), X1.P$48 (48), X2.28, X2.29
unnamed: X1.P$49 (49), X1.P$50 (50), X2.26, X2.27
unnamed: X1.P$11 (11), X2.56
unnamed: X1.P$9 (9), X2.58
unnamed: X1.P$7 (7), X2.68
unnamed: X1.P$5 (5), X2.70
unnamed: LED1.1, R2.2
unnamed: X1.P$6 (6), X2.71
unnamed: X1.P$8 (8), X2.69
unnamed: X1.P$10 (10), X2.67
unnamed: X1.P$20 (20), X2.57


Board: 4 copper layers, 24.0 x 60.0 mm, 5 parts (0 on the bottom side), 39 nets.

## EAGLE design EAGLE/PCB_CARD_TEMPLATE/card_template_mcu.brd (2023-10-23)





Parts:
M1: MOUNTING_3M_3.2MM
X1: CONN_SMD_67P-P0.5-V_NASB0-S6701-TS50
X2: M.2_MKEY_FINGERS

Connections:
+3V3: X1.P$1 (1), X2.74
GND: X1.P$75 (75), X2.1
unnamed: X1.P$23 (23), X2.52
unnamed: X1.P$25 (25), X2.50
unnamed: X1.P$73 (73), X2.2
unnamed: X1.P$71 (71), X2.4
unnamed: X1.P$69 (69), X2.6
unnamed: X1.P$67 (67), X2.8
unnamed: X1.P$65 (65), X2.10
unnamed: X1.P$63 (63), X2.12
unnamed: X1.P$61 (61), X2.14
unnamed: X1.P$59 (59), X2.16
unnamed: X1.P$57 (57), X2.18
unnamed: X1.P$55 (55), X2.20
unnamed: X1.P$53 (53), X2.22
unnamed: X1.P$51 (51), X2.24
unnamed: X1.P$21 (21), X2.54
unnamed: X1.P$27 (27), X2.48
unnamed: X1.P$29 (29), X2.46
unnamed: X1.P$31 (31), X2.44
unnamed: X1.P$33 (33), X2.42
unnamed: X1.P$35 (35), X2.40
unnamed: X1.P$37 (37), X2.38
unnamed: X1.P$39 (39), X2.36
unnamed: X1.P$41 (41), X2.34
unnamed: X1.P$43 (43), X2.32
unnamed: X1.P$45 (45), X2.30
unnamed: X1.P$47 (47), X2.28
unnamed: X1.P$49 (49), X2.26
unnamed: X1.P$11 (11), X2.56
unnamed: X1.P$9 (9), X2.58
unnamed: X1.P$7 (7), X2.68
unnamed: X1.P$5 (5), X2.70
unnamed: X1.P$3 (3), X2.72
unnamed: X1.P$2 (2), X2.75
unnamed: X1.P$22 (22), X2.55
unnamed: X1.P$4 (4), X2.73
unnamed: X1.P$6 (6), X2.71
unnamed: X1.P$8 (8), X2.69
unnamed: X1.P$10 (10), X2.67
unnamed: X1.P$20 (20), X2.57
unnamed: X1.P$24 (24), X2.53
unnamed: X1.P$26 (26), X2.51
unnamed: X1.P$28 (28), X2.49
unnamed: X1.P$30 (30), X2.47
unnamed: X1.P$32 (32), X2.45
unnamed: X1.P$34 (34), X2.43
unnamed: X1.P$36 (36), X2.41
unnamed: X1.P$38 (38), X2.39
unnamed: X1.P$40 (40), X2.37
unnamed: X1.P$42 (42), X2.35
unnamed: X1.P$44 (44), X2.33
unnamed: X1.P$74 (74), X2.3
unnamed: X1.P$72 (72), X2.5
unnamed: X1.P$70 (70), X2.7
unnamed: X1.P$68 (68), X2.9
unnamed: X1.P$66 (66), X2.11
unnamed: X1.P$64 (64), X2.13
unnamed: X1.P$62 (62), X2.15
unnamed: X1.P$60 (60), X2.17
unnamed: X1.P$58 (58), X2.19
unnamed: X1.P$56 (56), X2.21
unnamed: X1.P$54 (54), X2.23
unnamed: X1.P$52 (52), X2.25
unnamed: X1.P$46 (46), X2.31
unnamed: X1.P$48 (48), X2.29
unnamed: X1.P$50 (50), X2.27


Board: 4 copper layers, 24.0 x 60.0 mm, 3 parts (0 on the bottom side), 67 nets.

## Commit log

2023-10-11 First commit. WORK IN PROGRESS
    [BOM-Card_ESP32.csv, BOM-Chimera_0002_thea.csv, BOM-Chimera_0003_Hydra.csv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]
2023-10-11 Cleaned up folders
    [BOM-Chimera_0005_Stepper.csv, BOM-Chimera_Card_Template_2.csv, Chimera_0002_thea.kicad_pcb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]
2023-10-11 Added Nimean Pin description document
    [Nimean_0001_pin_description.xlsx]
2023-10-12 added Kicad JLC workflow document
2023-10-12 start eagle port
    [card_template.brd, card_template.sch]
2023-10-13 have footprints complete
    [card_template.brd, card_template.sch]
2023-10-17 added board settings, including design rules, to the accessory card template board file.
2023-10-17 completed accessory card template
    [card_template.brd, card_template.sch]
2023-10-18 finish mcu card template
    [card_template_mcu.brd, card_template_mcu.sch]
2023-10-18 Connected air wire on pad 47 of the card_template
    [Chimera_Card_Template.kicad_sch.kicad_pcb]
2023-10-18 Moved board into title block border. for Chimera_Card_template
    [Chimera_Card_Template.kicad_sch.kicad_pcb]
2023-10-18 start pic24 card
    [pic24_card.brd, pic24_card.sch]
2023-10-19 finished breaking out pic pins up near connector
    [pic24_card.brd]
2023-10-19 cleaned up model_chimera_card_holder folder and updated card holder model.
    [Chimera_Card_Holder v1.stl, Chimera_Card_Holder_03.step, Chimera_Card_Holder_03.stl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]
2023-10-19 pic24 card is done, gerbers and jlc files generated
    [PIC24_MCU_pin_description.xlsx, card_template.brd, card_template.sch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]
2023-10-23 finish pwr supply card
    [card_template.sch, power_supply_card.brd, power_supply_card.sch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]

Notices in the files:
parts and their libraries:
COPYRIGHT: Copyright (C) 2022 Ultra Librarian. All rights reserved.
